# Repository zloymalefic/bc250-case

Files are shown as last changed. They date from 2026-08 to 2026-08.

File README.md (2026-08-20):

# BC-250 + JF13K compact case

Engineering project for a compact, quiet, 3D-printable Steam Machine-style enclosure built around:

`AMD BC-250 + mounting adapter + JIUSHARK JF13K + modular PSU`

The design is in a controlled recovery and geometry-validation phase. There is currently no printable enclosure release. Previous prototype exports were withdrawn because their mating interfaces did not form a buildable assembly; see [cad/ASSEMBLY-AUDIT.md](cad/ASSEMBLY-AUDIT.md).

## Based on and inspired by

This enclosure is explicitly based on and inspired by two primary community projects:

- [nyacom's AMD BC-250 Industrial Style Case for FlexATX](https://www.printables.com/model/1737913-nyacoms-amd-bc-250-industrial-style-case-for-flexa) - primary exterior design, proportions, end-ring language, and removable-cover concept;
- [NexGen3D DIY Steam Machine PRO V2](https://www.printables.com/model/1793043-nexgen3d-diy-steam-machine-pro-v2-liquid-cooled-bc/files) - power-button assembly, serviceable snap/slot panels, universal PSU mounting strategy, and modular internal architecture.

The later [NexGen3D REDUX Edition](https://www.printables.com/model/1649679-nexgen3d-diy-steam-machine-redux-edition) is retained as a revision cross-check for mechanisms already adopted from PRO V2, plus its editable blank button and later storage/split-cover refinements.

Additional source projects, direct links, adopted features, pinned revisions, and licensing notes are documented in [ATTRIBUTION.md](ATTRIBUTION.md) and [SOURCES.md](SOURCES.md). This is an independent community derivative and is not an official product of the referenced creators or hardware vendors.

## Current direction

- Common chassis for the BC-250 and JF13K assembly.
- Replaceable horizontal and vertical support/base modules.
- Independent replaceable PSU carriers, initially for Cisco UCSC-PSU-650W V02 and later FlexATX.
- Vertical BC-250/JF13K assembly with controlled intake through the broad side panel.
- Serviceable front USB hub, 2.5-inch drive mount, and ESP32 relay-controller tray.

## Интерактивная 3D-визуализация

В репозитории есть браузерный viewer текущей компоновки корпуса. Он позволяет
вращать сборку, разносить детали, переключать заднюю крышку и независимо
скрывать элементы через легенду.

### Быстрый запуск

Требуются Python 3.10+ и современный браузер с WebGL 2. Для обычного просмотра
OpenSCAD не нужен: viewer использует готовые STL из `visualization/assets/`.

```sh
git clone <URL-РЕПОЗИТОРИЯ> bc250-case
cd bc250-case
python3 tools/dev_visualization.py
```

Открыть <http://localhost:8000/visualization/>. Сервер доступен только локально
на `127.0.0.1`. Для остановки нажать `Ctrl+C`. Другой порт:

```sh
python3 tools/dev_visualization.py --port 8080
```

Three.js загружается с jsDelivr, поэтому при первом открытии страницы требуется
доступ в интернет. Открывать `visualization/index.html` через `file://` нельзя:
браузер заблокирует загрузку STL.

### Управление viewer

- ЛКМ — вращение, колесо — масштаб, ПКМ — сдвиг камеры.
- Кнопки «Спереди», «Сбоку», «Сзади» и «3/4» выбирают готовый ракурс.
- «Разнести детали» показывает взаимное расположение компонентов.
- «Каркас корпуса» и «Внутренние компоненты» управляют крупными слоями.
- Каждая строка легенды отдельно скрывает или показывает соответствующий элемент.
- В блоке «Задняя крышка» выбирается горизонтальный, вертикальный вариант либо
  полностью снятая крышка.

### Обновление моделей

`cad/` и `cad-visualization/` являются исходниками, а
`visualization/assets/*.stl` — производными файлами только для рендеринга.
Обычный сервер не запускает OpenSCAD и не пересобирает CAD автоматически.

Полная сверка и обновление производных STL выполняются только явно:

```sh
tools/up-model
```

Команда собирает модели во временном каталоге, сравнивает геометрию и атомарно
заменяет только отличающиеся файлы в `visualization/assets/`. Исходные каталоги
она не изменяет. Проверка без замены файлов:

```sh
tools/up-model --check
```

Для пересборки требуется OpenSCAD в `PATH`. Установка на macOS:

```sh
brew install --cask openscad
```

На Ubuntu/Debian: `sudo apt install openscad`. Ручной совместимый entrypoint —
`tools/export_visualization_assets.sh`. После обновления STL запущенный viewer
сам перезагрузит страницу. Цвета и расположение объектов на сцене задаются в
`visualization/viewer.js` и не требуют изменения или повторного экспорта STL.

Полная инструкция, включая установку внешней mesh-модели BC-250 и решение
типичных проблем: [visualization/SETUP.md](visualization/SETUP.md).

Согласованные проекции корпуса v0.3

## Project files

- `BC-250-JF13K-agent-context.md` - original project context and priorities.
- `DESIGN-BRIEF.md` - evolving engineering requirements plus mandatory
  enclosure-envelope, mating-interface, physical-support, structural-strength,
  and airflow validation rules.
- `BOM.md` - provisional fastener, consumable, filament, electronics, and procurement list with project article numbers and quantities.
- `SOURCES.md` - reference registry, pinned revisions, formats, licenses, and preliminary measurements.
- `ATTRIBUTION.md` - complete credits, direct links, adopted features, and derivative-license notices.
- `docs/FINAL-VISUALIZATION.md` - final Blender/GLB rendering, viewing, and exploded-view delivery plan.
- `TECHNICAL-REPORT-01.md` - superseded horizontal layout study retained as design history.
- `cad/layout-a-envelope.scad` - parameterized collision/envelope model for layout A.
- `cad/exterior-nyacom-v0.2.scad` - replacement exterior direction closely based on the Nyacom industrial case language.
- `cad/NYACOM-ADAPTATION.md` - retained design features, necessary JF13K changes, and derivative-license note.
- `cad/JF13K-PHOTO-FIT.md` - official JF13K envelope, photo/board-model cross-check,
  panel clearance, and remaining physical sanity checks.
- `cad/power-button-nexgen-v0.1.scad` - recreated three-part, backlit, rotatable NexGen-style button module.
- `cad/psu-universal-internal-v0.2.scad` - internal receiver for the common
  NexGen 110 × 46.34 mm server/FlexATX/LOP adapter family.
- `cad/NEXGEN-MECHANISMS.md` - exact NexGen mechanisms selected for reuse and their project-specific constraints.
- `cad/PSU-INTERFACE.md` - fully internal PSU interface and flush-rear requirement.
- `cad/chassis-split-v0.1.scad` - front/rear printable structural sections with an internal alignment collar.
- `cad/CHASSIS-SPLIT.md` - split location, print envelopes, clearance, and retention details.
- `cad/chassis-joint-coupon-v0.1.scad` - reduced-cost three-clearance test of the real chamfered chassis joint.
- `cad/intake-panel-snap-v0.1.scad` - two independently replaceable JF13K intake halves with hidden hooks.
- `cad/fit-calibration-coupon-v0.1.scad` - combined M3/M4 insert, screw-hole, and snap-clearance pre-production test.
- `cad/front-service-module-v0.1.scad` - full-section sculpted Nyacom-derived front cap with an integrated NexGen button and USB cassette.
- `cad/rear-service-blanks-v0.1.scad` - two vertical snap-in board/I/O and PSU
  blanks shared by both rear-cover variants.
- `cad/board-spine-v0.1.scad` - split vertical BC-250 carrier using the verified
  308.0 × 144.3 mm bare-PCB envelope and an open backplate area.
- `cad/BC250-DATUM.md` - dimensional source audit and restricted-reference
  handling rules.
- `docs/JF13K-MEASUREMENT-GUIDE.md` - step-by-step Russian measurement and photo
  checklist for an already assembled BC-250 + JF13K module.
- `cad/USB-RETURN-INTERFACE.md` - dual 180-degree adapter envelope and the
  replaceable-insert rule derived from NexGen and seller data.
- `cad/peripheral-bay-v0.1.scad` - removable 7 mm SSD and ESP32 relay-board cassettes.
- `cad/REAR-COVER-VARIANTS.md` - shared portrait I/O/PSU openings and the
  horizontal versus tapered vertical rear-cover construction.
- `cad/ASSEMBLY-AUDIT.md` - authoritative compatibility audit and recovery order.
- `cad/core-assembly-v0.1.scad` - active single-source rebuild of the two-part structural core and accessible seam retention.
- `cad/CORE-ASSEMBLY.md` - core assembly sequence, closed interfaces, and remaining work.
- `cad/REDUX-ADAPTATION.md` - selected Redux mechanisms, measured envelopes, and adaptation constraints.
- `cad/exports/README.md` - authoritative list of STL files currently approved for slicing.
- `cad/support-horizontal.scad` and `cad/support-vertical.scad` - interchangeable support prototypes using a common M4 interface.
- `cad/SUPPORT-INTERFACE.md` - dimensions, fasteners, and unresolved validation points for both orientations.
- `cad/previews/exterior-orthographic-v0.3.svg` - four orthographic projections
  at one scale plus a tower-orientation schematic derived from the left view.
- `references/printables-*` - downloaded reference models retained with their source PDFs and license information.
- `tools/inspect_3mf.py` - small utility for reporting raw 3MF vertex bounds.

## Important

The repository contains third-party reference files under different licenses. Review `SOURCES.md` and the source PDF in each reference directory before reusing or redistributing a model. Reference geometry is not automatically part of the final case design.

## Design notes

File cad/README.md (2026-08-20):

# CAD workspace

Current status: **design recovery; no printable enclosure release**.

## Verification before printing

Run `python3 tools/verify_model.py` from the repository root. It compiles the
assembly constraints and checks nine critical generated STL files for contract
envelopes, degenerate triangles, open/non-manifold edges and the 250 mm print
ceiling. Only `MODEL VERIFICATION PASSED` is an acceptable result.

`tools/export_visualization_assets.sh` runs the same verification automatically.
All twenty parts are generated in a temporary directory first. Viewer assets
are replaced only after the complete set passes, so an invalid rebuild cannot
overwrite the last verified STL files.

Mechanical mating dimensions live in `lib/interface-contracts.scad`. The front
panel/button/USB interfaces, intake covers/gap/magnets, ESP32 cover/opening,
rear covers and universal PSU receiver consume these shared values.

Read `ASSEMBLY-AUDIT.md` before using any model. It records why the previous collection could not be assembled and defines the recovery order.

## Safe outputs

Only the small test pieces in `exports/` are currently approved for slicing. See `exports/README.md`.

```sh
openscad -o exports/fit-calibration-coupon-v0.1.stl fit-calibration-coupon-v0.1.scad
openscad -D 'clearances=[0.25]' -o exports/chassis-joint-coupon-0.25mm-v0.1.stl chassis-joint-coupon-v0.1.scad
openscad -D 'clearances=[0.35]' -o exports/chassis-joint-coupon-0.35mm-v0.1.stl chassis-joint-coupon-v0.1.scad
openscad -D 'clearances=[0.45]' -o exports/chassis-joint-coupon-0.45mm-v0.1.stl chassis-joint-coupon-v0.1.scad
```

## Retained studies

Other `.scad` files are non-release studies. They preserve useful dimensions and geometry for rebuilding the master assembly, but their interfaces are incomplete. Successful OpenSCAD compilation does not make a study printable or compatible with another study.

The exterior direction is documented by
`previews/exterior-orthographic-v0.3.svg`: four separate orthographic views at a
common 2 px/mm scale and a tower schematic obtained by rotating the left-side
projection. It is a dimensional architecture preview, not a manufacturing
drawing.

## Active rebuild

`core-assembly-v0.1.scad` is the active master for the two structural halves. It replaces the inaccessible axial joint with two bottom-access M3 fasteners. See `CORE-ASSEMBLY.md`. It remains validation-only until end panels and internal mounting interfaces are integrated.

The same master now includes two interchangeable rear-cover structures:
`rear-cover-horizontal` and `rear-cover-vertical`. The latter becomes a 44 mm
open cable-management base when the complete enclosure is stood on its rear
face. See `REAR-COVER-VARIANTS.md`.

`HEATSINK-MOUNT-COMPARISON.md` compares the supplied Sean MK7/RZ620 mount with
the previously supplied AN600 adapter and records why neither may yet be treated
as a verified JF13K production mount.

`board-spine-v0.1.scad` is the first dimensional vertical carrier based on the
308.0 × 144.3 × 1.6 mm bare-PCB envelope. `BC250-DATUM.md` records the source,
license boundary, open-reference cross-check, and remaining retention risk.

`psu-universal-internal-v0.2.scad` replaces the provisional long rail with a
fully internal receiver for the NexGen 110 × 46.34 mm interchangeable PSU mount
family. It accepts server, FlexATX, and Mean Well plate depths without requiring
the Cisco PSU body to be measured.

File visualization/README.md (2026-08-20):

# BC-250 browser 3D viewer

Русская инструкция по установке и совместной работе: [`SETUP.md`](SETUP.md).

Быстрый запуск из корня репозитория:

```sh
python3 tools/dev_visualization.py
```

Открыть: <http://localhost:8000/visualization/>

Сервер следит за интерфейсом и готовыми STL и автоматически обновляет открытую
страницу. CAD автоматически не пересобирается.

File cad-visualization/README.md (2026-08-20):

# Visualization-only CAD sources

This directory contains non-printable geometry used only to prepare browser
rendering assets. Files here must not be treated as manufacturing models.

- `cad/` is the authoritative engineering CAD source.
- `cad-visualization/` contains visualization-only wrappers and decorative meshes.
- `visualization/assets/` contains generated render assets and is never authoritative.

The visualization agent treats both `cad/` and `cad-visualization/` as
read-only. Missing or incompatible source geometry must be reported instead of
being silently replaced or adjusted for appearance.

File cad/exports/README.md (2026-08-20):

# Validation exports only

There is currently no printable case release in this directory.

The retained files are small calibration objects:

- `fit-calibration-coupon-v0.1.stl` — M3/M4 holes, heat-set pilots, and snap clearances;
- `chassis-joint-coupon-0.25mm-v0.1.stl`;
- `chassis-joint-coupon-0.35mm-v0.1.stl`;
- `chassis-joint-coupon-0.45mm-v0.1.stl`.

Do not combine these into a case assembly. Release parts will appear under `exports/release/<version>/` only after a complete master-assembly check.

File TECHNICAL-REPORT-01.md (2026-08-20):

# Первый технический отчёт: BC-250 + JF13K — устаревшая компоновка

> Отменено 2026-08-20. В выбранной архитектуре Nyacom плата BC-250 и основные компоненты установлены вертикально вдоль длинной оси корпуса. Горизонтальная двухуровневая рекомендация ниже сохранена только как история исследования и не должна использоваться в текущем CAD.

Дата: 2026-08-19  
Статус: компоновочное исследование до физического fit-check.

## 1. Вывод

Рекомендуемая архитектура — **продольный двухуровневый chassis**: BC-250 и JF13K образуют верхний функциональный модуль, а Cisco PSU устанавливается вдоль платы в отдельном нижнем канале. Горизонтальная и вертикальная версии используют один chassis и отличаются только внешней опорой/нижней панелью. PSU, SSD и контроллер питания устанавливаются на отдельных сменных кассетах.

Предварительный внешний envelope рекомендуемой версии: **около 330 × 155 × 195 мм, 10,0 л**. Поперечное сечение сделано уже и выше, чтобы сохранить характерные пропорции Nyacom вместо квадратного тоннеля. Размер всё ещё предварительный: высота зависит от фактической установки кулера и разъёмов Cisco PSU.

## 2. Таблица размеров

| Узел | Размер, мм | Статус | Источник / примечание |
|---|---:|---|---|
| BC-250, proxy-envelope с компонентами | 311,7 × 144 × 31,8 | подтверждено по локальной mesh-модели | `references/hafriedlander-bc250-case/_extern/bc250_alt.stl`; требует сверки с независимым STEP |
| JIUSHARK JF13K Diamond | 241 × 121 × 92 | подтверждено производителем | https://www.jiushark.com/products/jf13k.html |
| JF13K, масса | 895 г | подтверждено производителем | тот же источник |
| JF13K, вентиляторы | 2 × 120 × 120 × 15 | подтверждено производителем | тот же источник |
| AN600-to-BC250 adapter | 105 × 105 × 8 | подтверждено по STL и 3MF | Printables 1707972, обе модели совпадают по bounds |
| Cisco UCSC-PSU-650W V02 | около 240 × 96 × 40 | предварительно | открытые источники смешивают близкие DPS-650AB-2 revisions; обязательно измерить экземпляр |
| 2,5″ накопитель | около 100 × 70 × 7–15 | стандартный envelope | точная толщина зависит от устройства |
| ESP32-WROOM + 2 relay PCB | до 60 × 60 | предварительно по карточке товара | отверстия и высоту клемм измерить после покупки |
| Nyacom FlexATX reference case | 125 × 315 × 175 | подтверждено по STL envelope | около 6,9 л, штатный heatsink |
| NexGen PRO V2 reference case | около 329 × 109 × 282 | расчёт по отдельным 3MF | около 10,15 л; сборочные transforms требуют осторожности |
| Quiet Tower reference case | 180 × 368 × 269 | подтверждено по assembled STL | около 17,8 л |

## 3. Envelope узла BC-250 + adapter + JF13K

### Плановая проекция

- BC-250 proxy-envelope: 311,7 × 144 мм.
- JF13K: 241 × 121 мм.
- При подтверждённой параллельной установке JF13K кулер должен помещаться внутри продольного envelope платы либо давать небольшое локальное нависание, не определяющее полную длину корпуса.
- Минимальный расчётный внутренний план chassis: **320 × 150 мм**.
- Практический план с рёбрами, панелями и допусками: **325–330 × 160–170 мм**.

### Высота

- Номинальные 92 мм JF13K относятся к стандартной socket installation.
- Адаптер имеет толщину 8 мм, но нельзя просто сложить 92 + 8: часть высоты входит в монтажный stack и зависит от планок, проставок и coldplate.
- До измерения использовать расчётный front-side envelope **100–110 мм от плоскости PCB**.
- Под PCB требуется 12–18 мм для backplate, электрических зазоров и воздушного канала.
- Без PSU расчётная толщина модуля: **115–130 мм**.

### Сервисные зоны

- Не менее 15 мм около силового 8-pin разъёма до начала радиуса изгиба углового адаптера/кабеля.
- Съёмная панель над крепёжными точками либо возможность вынуть весь tray платы без снятия JF13K.
- Зона отвёртки зависит от того, затягивается ли JF13K со стороны backplate; доступ должен сохраняться до установки нижнего PSU-tray.
- Локальная ниша под 180°/90° USB-A адаптер с механической разгрузкой порта.

## 4. Совместимость AN600 adapter с JF13K

### Что подтверждено

- Адаптер связывает четыре точки BC-250 с Intel mounting bars от AN600.
- JF13K комплектуется Intel LGA1700 bars и использует заднюю затяжку.
- В сообществе показана работоспособная установка JF13K на BC-250 через LGA1700-to-BC250 adapter.

### Что не подтверждено

- Совпадение отверстий Intel bars JF13K с внутренними отверстиями конкретного STL AN600.
- Возможность использовать STL без снятия чёрных элементов штатного крепления.
- Толщина проставок: в практическом сообщении упомянуты четыре spacer 1–2 мм.
- Длина винтов, остаточный ход пружин и допустимое усилие прижима.
- Полный контакт coldplate с APU без перекоса.

### Инженерный вывод

Совместимость **условно подтверждена на уровне монтажного принципа**, но не подтверждена для неизменённого комплекта деталей. Первый печатный объект проекта должен быть не корпусом, а адаптером и набором калибровочных проставок 1,0 / 1,5 / 2,0 мм.

## 5. Варианты компоновки

### A. Продольный двухуровневый chassis — рекомендация

Ориентировочный размер: **330 × 155 × 195 мм (~10,0 л)**.

- BC-250 + JF13K сверху.
- Cisco PSU продольно под PCB, ближе к одному краю.
- Рядом с PSU в нижнем канале: ESP32 relay tray и опциональный 2,5″ tray.
- JF13K получает воздух через большую верхнюю/боковую mesh-панель.
- Горячий воздух выходит через торцы и контролируемую зону вокруг I/O.
- PSU получает собственный холодный воздух снизу/сзади и не питается выхлопом JF13K.
- Горизонтальная версия использует ножки и нижнюю панель; вертикальная — сменную широкую опору на короткой грани.

Плюсы: компактность, короткие силовые кабели, общий chassis для двух ориентаций, хорошая защита тяжёлого кулера.  
Риски: общая высота; нужно изолировать intake PSU от backplate exhaust; обслуживание нижнего канала требует отдельной крышки.

### B. Плоский sidecar

Ориентировочный размер: **330 × 265 × 125 мм (~10,9 л)**.

- PSU расположен рядом с BC-250 в одной плоскости.
- JF13K остаётся единственным высоким узлом.
- SSD и ESP32 размещаются в полосе между PSU и I/O либо на съёмной поперечной балке.
- Intake JF13K и PSU полностью независимы.

Плюсы: минимальная толщина, лучший сервисный доступ, простые воздушные каналы.  
Риски: большая площадь на столе, менее выразительная вертикальная версия, длиннее силовая трасса, сложнее уложиться в типовой стол 250 мм одной крупной деталью.

### C. Полуоткрытый PSU-spine

Ориентировочный bounding box: **330 × 210 × 135 мм (~9,4 л)**, форма неполного прямоугольника.

- Основной модуль BC-250 + JF13K остаётся тонким.
- Cisco PSU находится в выступающем внешнем spine/кассете вдоль заднего края.
- Spine одновременно является ручкой/силовой балкой и меняется на FlexATX-модуль.
- SSD и ESP32 находятся за отдельной сервисной крышкой в spine.

Плюсы: лучший доступ к PSU, минимальная тепловая связь, простая замена PSU.  
Риски: хуже внешний вид, выступ усложняет вертикальную опору, больше риск повреждения PSU/разъёмов при переноске, сложнее обеспечить общую жёсткость.

## 6. Airflow рекомендуемой архитектуры

Основной поток:

`наружный воздух → mesh с зазором 7–10 мм → 2×120 мм JF13K → радиатор → лицевая сторона BC-250 → торцевые exhaust-зоны`

Отдельный нижний поток:

`нижний/задний intake → Cisco PSU → собственный exhaust наружу`

Backplate:

- под PCB оставить непрерывный канал высотой 12–18 мм;
- часть давления после JF13K направить в входные окна канала;
- предусмотреть, но не комплектовать, место под 80/92-мм вентилятор;
- решение об установке вентилятора принимать после температуры backplate/памяти.

## 7. Переиспользуемые решения

### Из Nyacom

- двухчастный продольный корпус;
- магнитная декоративная панель и направляющие;
- скользящее крепление 2,5″/3,5″ как принцип;
- отдельные варианты панелей и резервный backplate fan mount.

Прямое копирование деталей ограничено CC BY-NC-SA и несовместимой геометрией штатного охлаждения.

### Из NexGen PRO V2

- единое внутреннее PSU-шасси со сменными адаптерами; в нашей реализации оно полностью утоплено в корпус;
- обязательная access panel на скрытых защёлках, без внешних болтов;
- трёхдетальная поворотная кнопка с подсветкой;
- сменные faceplates;
- щелевые вертикальные/горизонтальные опоры;
- multipurpose bay для USB/SSD/ESP;
- резьбовые вставки и повторяемый M3-крепёж.

Прямое копирование ограничено CC BY-NC; архитектурные принципы будут реализованы заново.

### Новые детали

- несущий chassis под JF13K;
- усиленный board tray и транспортные упоры кулера;
- intake panel на 2×120 мм;
- канал backplate;
- кассета Cisco UCSC-PSU-650W V02;
- кассета FlexATX;
- horizontal base и vertical stand;
- USB-hub faceplate и фиксатор углового USB adapter;
- ESP32 relay tray;
- адаптер/проставки JF13K.

## 8. Риски

| Риск | Мера |
|---|---|
| Изгиб PCB от 895-граммового JF13K | жёсткий perimeter tray, backplate load spreader, транспортные упоры радиатора |
| Неравномерный прижим APU | калибровочные проставки, контролируемая последовательность затяжки, проверка отпечатка TIM |
| Горячая обратная сторона/память | канал 12–18 мм, датчики, резерв 80/92 мм |
| Рециркуляция | разделённые intake/exhaust, уплотнение вокруг JF13K intake |
| Шум mesh | свободная площадь ≥1,5× площади вентиляторов, скруглённые ячейки, тест зазора 7/10/15 мм |
| Шум server PSU | независимый intake; не модифицировать вентилятор до измерения температуры и PWM behavior |
| Повреждение USB порта | печатный фиксатор углового адаптера и strain relief кабеля |
| Недоступность конкретного USB hub | сменная малая faceplate/cassette |

## 9. План open-bench испытаний

1. Fit-check адаптера без включения: отверстия, coldplate, зазоры, полный ход винтов.
2. Проверка отпечатка термоинтерфейса и параллельности coldplate.
3. Горизонтальный open-bench: 15 минут idle, 30 минут игровая нагрузка, 20 минут комбинированная CPU+GPU нагрузка.
4. Повторить вертикально, контролируя изменение контакта и изгиб.
5. Логировать APU/GPU, доступные VRM/board sensors, NVMe, обороты обоих JF13K fans и PSU.
6. Измерять backplate термопарой/термистором минимум в центре и около памяти; ИК-камера полезна, но не заменяет контактный датчик на блестящем металле.
7. Шум измерять с 0,5 м и 1 м, фиксируя фон помещения и обороты.
8. Сравнить mesh gaps 7 / 10 / 15 мм и временно закрывать альтернативные exhaust-зоны для выявления рециркуляции.
9. Критерий дополнительного 80/92-мм вентилятора: устойчивое улучшение backplate/памяти без заметного роста шума и без ухудшения APU.

## 10. Неизвестные параметры

- фактическая высота JF13K над PCB с этим адаптером;
- точные JF13K mounting-bar отверстия и винты;
- фактическое направление airflow Cisco PSU; механическая посадка теперь
  выполняется через универсальный адаптер NexGen 110 × 46,34 мм без обмера корпуса;
- положение JF13K относительно концов PCB и I/O;
- изгиб/радиус реального 8-pin кабеля;
- габариты выбранного USB hub;
- размеры ESP32 relay PCB и клемм;
- желаемый максимум внешнего объёма и массы корпуса.

## 11. Решение до получения новых данных

Продолжать с архитектурой A как baseline, но CAD вести параметрически. Не фиксировать высоту корпуса и отверстия JF13K до фотографий/измерений установленного узла. Первым прототипом сделать adapter fit-check, вторым — плоский board tray с каналом backplate, третьим — PSU cassette. Полный декоративный корпус печатать только после этих трёх проверок.

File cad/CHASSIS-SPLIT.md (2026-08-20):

# Split chassis interface v0.1

> Historical prototype. The released working source is now
> `core-assembly-v0.1.scad`; its split intake, central rib and receiver pockets
> supersede the single 266 × 119 mm opening described below.

The 330 mm Nyacom-style structural tunnel is divided at X=165 mm:

- front section nominal print envelope: 174 × 155 × 195 mm, including its alignment collar;
- rear section nominal print envelope: 165 × 155 × 195 mm;
- both fit within the preliminary 250 × 250 × 250 mm part limit;
- a 9 mm internal octagonal collar aligns all eight shell faces;
- the collar overlaps 1.2 mm into the front shell so it is one fused printable solid rather than a coincident mesh;
- initial radial assembly clearance is 0.35 mm per side;
- the current axial M3 bosses are an obsolete prototype and will be replaced by bottom-access fasteners close to the seam.

## Functional interfaces added

- JF13K intake opening: 266 × 119 mm;
- eight magnet bosses matching the two four-magnet intake panels, plus four longitudinal guide tongues;
- receiver blocks are integrated into the inner top perimeter, not glued-on parts;
- continuous internal tray ledges run along both lower side walls;
- ledge top is Z=49 mm, matching the integrated board-tray origin;
- the intake opening and magnet pattern cross the chassis split without placing a pocket directly on the joint.
- four 13 mm reinforced floor bosses provide the corrected 258 × 99 mm horizontal-support pattern;
- bosses accept M4 clearance screws and provisional 5.6 mm heat-set-insert pilots installed from inside.

The collar clearance is provisional. Before rebuilding complete shell exports, print the three `exports/chassis-joint-coupon-*-v0.1.stl` pairs at 0.25, 0.35, and 0.45 mm clearance per side.

Magnet-pocket allowance remains provisional. Full chassis printing must wait until an 8.25 × 2.20 mm pocket coupon is tested with the selected material, print service, magnet coating and adhesive.

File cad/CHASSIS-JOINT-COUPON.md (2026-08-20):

# Chassis joint coupon v0.1

The complete chassis sections are too large and expensive to use as calibration prints. `chassis-joint-coupon-v0.1.scad` therefore extracts the actual bottom-left chamfered corner of the shell and collar.

The export set contains three labelled STL files, each with one male/female pair. Their radial clearances are 0.25, 0.35, and 0.45 mm per side. Every pair includes the real 4 mm shell, 2.4 mm collar wall, chamfer transition, 9 mm insertion length, and a fused anchor extending 1.2 mm into the front shell.

## Procedure

1. Print the three `chassis-joint-coupon-*-v0.1.stl` files together; each file is one matched pair.
2. Print using the final chassis material, orientation, layer height, wall count, and cooling settings.
3. Deburr only the same way planned for production; do not sand a poor fit into compliance.
4. Insert fully, separate, and repeat at least ten times.
5. Select the smallest clearance that seats fully by hand without cracking, whitening, or rocking after repeated cycles.
6. Record the result in the table and update `collar_clearance` in `chassis-split-v0.1.scad`.

| Clearance per side | Seats fully | Releases cleanly | Visible play | Damage after 10 cycles | Decision |
|---:|---|---|---|---|---|
| 0.25 mm | — | — | — | — | — |
| 0.35 mm | — | — | — | — | — |
| 0.45 mm | — | — | — | — | — |

The obsolete axial M3 boss concept is intentionally absent. A production screw cannot practically be inserted along the full enclosure length. Structural retention will use bottom-access fasteners close to the seam and remain hidden by the horizontal or vertical support system.

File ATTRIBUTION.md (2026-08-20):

# Credits, inspiration, and attribution

This project is not designed in isolation. It is based on, adapted from, and inspired by the BC-250 community projects listed below. Their authors established much of the visual language, service architecture, mounting strategy, and source geometry used during development.

## Primary exterior reference

### nyacom - AMD BC-250 Industrial Style Case for FlexATX

- Source: https://www.printables.com/model/1737913-nyacoms-amd-bc-250-industrial-style-case-for-flexa
- License: CC BY-NC-SA 4.0, as identified in the supplied Printables package.
- Used for: industrial exterior language, long octagonal tunnel, contrasting end rings, recessed end panels, removable broad-side cover, sliding storage-mount principle, and general compact proportions.
- Project-specific adaptation: enlarged and restructured around the JIUSHARK JF13K, split for smaller print beds, and combined with NexGen-derived service mechanisms.

## Primary mechanical reference

### NexGen-3D-Printing - DIY Steam Machine REDUX Edition (later revision cross-check)

- Source: https://www.printables.com/model/1649679-nexgen3d-diy-steam-machine-redux-edition
- License: CC BY-NC 4.0, as identified in the supplied package.
- Used to compare later revisions of mechanisms already adopted from PRO V2. Additional useful files are the editable blank button, improved snap tabs, split-cover joiners, and storage caddy.
- Adaptation notes: `cad/REDUX-ADAPTATION.md`.
- No Redux mesh is currently included in a release part.

### NexGen-3D-Printing - DIY Steam Machine PRO V2

- Printables files: https://www.printables.com/model/1793043-nexgen3d-diy-steam-machine-pro-v2-liquid-cooled-bc/files
- GitHub: https://github.com/NexGen-3D-Printing/SteamMachine
- License: CC BY-NC 4.0, as identified in the supplied Printables package.
- Used for: replaceable PSU mounts, internal multipurpose bay, access-panel strategy, snap/slot panel servicing, vertical and horizontal support concepts, and the three-part backlit power button.
- Directly reused asset: `Power Button/pro-v2-steam-logo.3mf`, retained in the local reference package and imported by `cad/power-button-nexgen-v0.1.scad`.
- Project-specific adaptation: the common PSU chassis is fully internal; no PSU carrier is allowed to protrude through the Nyacom-style rear ring.

## Additional geometry and engineering references

### hafriedlander - bc250-case

- Source: https://github.com/hafriedlander/bc250-case
- Used for: BC-250 proxy geometry, OpenSCAD construction study, and preliminary envelope validation.
- No standalone license was found in the pinned local revision; its geometry is therefore treated as an engineering reference and is not presented as original project geometry.

### onemorecap - bc-250-shell-case

- Source: https://github.com/onemorecap/bc-250-shell-case
- Used for: editable chassis, mounting, and print-splitting study.
- No standalone license was found in the pinned local revision; its geometry is treated as reference-only.

### DeepCool AN600 adapter for AMD BC-250

- Source: https://www.printables.com/model/1707972-deepcool-an600-adapter-for-amd-bc-250
- License: Public Domain, as identified in the supplied Printables package.
- Used for: the initial LGA1700-style cooler-interface study and JF13K fit-check planning.

### Sean - BC-250 Heat Sink Mount (MK7)

- Source: https://www.printables.com/model/1217021-bc-250-heat-sink-mount
- License: Public Domain, as identified in the supplied Printables PDF.
- Used for: independent BC-250 heatsink-footprint comparison and M4 fastening
  study. It is not treated as a JF13K-compatible production adapter.

### torassk - Accurate 3D Model of the AMD BC-250 Board

- Source: https://www.printables.com/model/1341336-accurate-3d-model-of-the-amd-bc-250-board
- License: Standard Digital File License in the supplied PDF.
- Used locally only to cross-check factual board dimensions. No source file,
  converted model, or linked derivative is hosted in this repository.

### BC-250 Quiet Case Tower Cooler

- Source: https://www.printables.com/model/1652979
- License: CC BY-NC 4.0, as identified in the supplied Printables package.
- Used for: front USB routing, large-air-cooler packaging, and auxiliary-storage study.

### zloymalefic - BC-250 PC Remote Control

- Source: https://github.com/zloymalefic/BC-250-PC-Remote-Control
- Used for: ESP32 relay-controller integration, remote power control, and front-button electrical planning.

## Project status and licensing note

The current repository contains engineering studies, recreated interfaces, derivative visual design, and third-party reference packages. It is not an official product of nyacom, NexGen-3D-Printing, Valve, AMD, ASRock, Cisco, or JIUSHARK.

Any distribution or remix of derivative case geometry must preserve the attribution, non-commercial, and share-alike obligations applicable to the Nyacom-derived portions. Direct NexGen assets, including the Steam-logo button component, retain their original attribution and license requirements. Review each source package before redistributing individual third-party files.

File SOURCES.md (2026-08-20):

# Реестр инженерных источников

Статус на 2026-08-19. Наличие файла не означает подтверждение его точности или разрешение на прямое переиспользование.

## Получено локально

| Источник | Форматы | Полезность | Статус лицензии |
|---|---|---|---|
| [hafriedlander/bc250-case](https://github.com/hafriedlander/bc250-case) | OpenSCAD, STL, изображения | Детальная proxy-модель BC-250, параметрический корпус, кронштейны | Отдельный LICENSE в репозитории не найден; прямое копирование деталей пока запрещено |
| [onemorecap/bc-250-shell-case](https://github.com/onemorecap/bc-250-shell-case) | STEP, 3MF, STL, изображения | Редактируемый модульный chassis, крепёж и разбиение для печати | Отдельный LICENSE в репозитории не найден; прямое копирование деталей пока запрещено |
| [NexGen-3D-Printing/SteamMachine](https://github.com/NexGen-3D-Printing/SteamMachine) | README, XLSX BOM, 3MF, архивы | Принципы модульности, PSU-модули, faceplates, обслуживание | CAD-пакет Printables: CC BY-NC 4.0 |
| [zloymalefic/BC-250-PC-Remote-Control](https://github.com/zloymalefic/BC-250-PC-Remote-Control) | Arduino/C++, HTML/CSS | Электрические интерфейсы контроллера питания и кнопки | Используется как связанный пользовательский проект; геометрия платы пока внешняя |

Зафиксированные ревизии:

- hafriedlander: `cf807f35897c43f5c489bf60b8fa54bf1fba0f00`;
- onemorecap: `ea2e59bab5ea5f5bd4cfce69b72c4a192391daea`;
- NexGen3D: `b305ccccd7133a7ae7340d578f10b4ec820ff63a`;
- Remote Control: `793f5d05ef1bef5f4681796562bda49f6b1ef97f`.

## Получено из Printables

### NexGen3D DIY Steam Machine REDUX Edition

- Source: https://www.printables.com/model/1649679-nexgen3d-diy-steam-machine-redux-edition
- Printables model 1649679; архив распакован в `references/printables-1649679-nexgen-redux`.
- 85 файлов: V4.2/V4.2.1 3MF, STEP-заготовки faceplate/button/PSU brackets, старые ревизии и PDF.
- Статус: более поздняя ревизия механизмов, уже принятых из PRO V2. Дополнительная ценность: editable blank-button STEP, обновлённые snap-tabs, split covers и storage caddy.
- `redux-optional-usb-cover.3mf`: raw envelope около 12,65 × 70,35 × 32,58 мм.
- Лицензия: CC BY-NC 4.0.

### Nyacom Industrial Style Case for FlexATX

- Source: https://www.printables.com/model/1737913-nyacoms-amd-bc-250-industrial-style-case-for-flexa
- Printables model 1737913; полный архив распакован в `references/printables-1737913-nyacom-flex`.
- 36 STL, 2 reference 3MF и 42-страничный PDF.
- Общий envelope корпуса по STL: около 125 × 315 × 175 мм (~6,9 л), без внешних кабелей и ножек.
- 3MF помечены автором как outdated/reference; актуальными считаются отдельные STL.
- Лицензия: CC BY-NC-SA 4.0.

### NexGen3D Steam Machine PRO V2

- Files: https://www.printables.com/model/1793043-nexgen3d-diy-steam-machine-pro-v2-liquid-cooled-bc/files
- Printables model 1793043; полный архив распакован в `references/printables-1793043-nexgen-pro-v2`.
- 43 файла 3MF, 1 редактируемый STEP пустой faceplate и 15-страничный PDF.
- Примерный общий envelope front + rear: 329,1 × 109,35 × 282,1 мм (~10,15 л); требует проверки сборочных transforms.
- Присутствуют отдельные крепления server PSU/FlexATX/LOP, вертикальная подставка, access panel и multipurpose bay.
- Лицензия: CC BY-NC 4.0.

### BC-250 Quiet Case Tower Cooler

- Source: https://www.printables.com/model/1652979
- Printables model 1652979; архив распакован в `references/printables-1652979-quiet-case`.
- Это дополнительный референс, а не запрошенный адаптер AN600.
- 16 STL и 7-страничный PDF; envelope assembled STL около 180 × 368 × 269 мм (~17,8 л).
- Полезен для USB routing, большого воздушного кулера и front USB hub.
- Лицензия: CC BY-NC 4.0.

### DeepCool AN600 adapter for AMD BC-250

- Source: https://www.printables.com/model/1707972-deepcool-an600-adapter-for-amd-bc-250
- Printables model 1707972; полный архив распакован в `references/printables-1707972-an600-adapter`.
- Содержит STL, 3MF и 3-страничный PDF; редактируемого STEP/CAD нет.
- STL и 3MF имеют совпадающий envelope 105 × 105 × 8 мм.
- Рассчитан на Intel mounting brackets из комплекта DeepCool AN600.
- Крепёж автора: 4× M3×12, 4× M3×20, 8× M3 nuts.
- Лицензия: Public Domain.

### Sean BC-250 Heat Sink Mount (MK7)

- Source: https://www.printables.com/model/1217021-bc-250-heat-sink-mount
- Printables model 1217021; supplied archive extracted to
  `references/printables-1217021-heatsink-mount`.
- Contains one 105.56 × 104.39 × 8 mm STL and a 2-page Printables PDF.
- Intended for the PCCOOLER RZ620 Intel clip bracket, not the JIUSHARK JF13K.
- Author describes M4 installation from below, either self-tapped or through
  with nuts, using a mixture of cooler and removed stock-heatsink hardware.
- License in supplied PDF: Public Domain.

### torassk Accurate 3D Model of the AMD BC-250 Board

- Source: https://www.printables.com/model/1341336-accurate-3d-model-of-the-amd-bc-250-board
- The user supplied the package locally; it is intentionally not extracted into
  or committed to this repository.
- Files: STEP, STL, and a 2-page Printables PDF.
- Author states that dimensions and mounting points match the real board.
- License: Standard Digital File License; no sharing, hosting, remixing, or
  redistribution. Used only as a local dimensional cross-check.

## Доступно в каталогах, но файлы ещё не получены

## Дополнительные источники геометрии BC-250

- Printables model 1341336: accurate 3D model of AMD BC-250.
- Printables model 1537364: AMD BC-250 STEP file.
- Полученная proxy-модель `references/hafriedlander-bc250-case/_extern/BC-250.scad` сгенерирована из FreeCAD и должна быть сверена с этими двумя источниками.

## Правило использования

До проверки лицензии и геометрии внешние модели применяются только для анализа envelope, интерфейсов и архитектурных принципов. Финальные детали не копируются из источника с неясной лицензией.

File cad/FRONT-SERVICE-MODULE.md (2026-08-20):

# Front service module v0.1

The yellow Nyacom-style front insert is now independent from both service components:

- front panel: full 155 × 195 × 12 mm sculpted end cap derived from the Nyacom source mesh, scaled only in its face plane to match this enclosure;
- NexGen-derived button opening: 45.2 × 32.3 mm;
- replaceable vertical USB cassette opening: 28.6 × 71.0 mm;
- cassette face: 27.93 × 70.35 × 3 mm;
- baseline hub: Anker A7516 four-port USB 3.0, 103 × 30 × 10 mm;
- front apertures: four vertical USB-A data ports;
- four front-access countersunk M3 screws retain the main panel on its support shoulder;
- the small USB cassette can be serviced after the four front-panel screws are removed;
- authoritative shape source: `references/printables-1737913-nyacom-flex/body-front-panel.stl`;
- the NexGen 44.5 × 31.6 mm mounting plate is fastened exclusively against the
  inside face; only the light pipe/pusher and logo cap pass through to the
  exterior. A separate extension accounts for the 12 mm cap thickness.
- concealed release notches permit servicing without visible screws.
- two M3 insert bosses and edge ribs retain the NexGen-derived button plate.

NexGen PRO V2 explicitly specifies the Anker four-port hub and its supplied USB
cover measures approximately 70.35 × 27.93 × 12.65 mm. This is the current
baseline. If a cheaper hub is selected later, only the small cassette is
reworked; the 28.6 × 71.0 mm front-panel interface and its receiver rails remain
unchanged wherever possible.

The rear USB return is now specified independently in `USB-RETURN-INTERFACE.md`.
Its provisional per-adapter envelope is 32 × 30 × 29 mm plus clearance; only a
small contact insert depends on the delivered A/D variant.

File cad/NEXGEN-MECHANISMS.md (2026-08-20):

# NexGen PRO V2 mechanisms adopted by this project

Only the mechanisms below are taken from the NexGen reference. Exterior styling remains based on Nyacom model 1737913.

## Rotatable power button

The supplied NexGen files separate the module into:

- mounting plate, measured raw envelope 44.54 × 31.59 × 5.10 mm;
- transparent rear/light-pipe section, 6.00 × 19.80 × 22.06 mm in its print orientation;
- removable Steam-emblem cap, 6.20 × 16.00 × 16.00 mm in its print orientation. The original `pro-v2-steam-logo.3mf` is imported directly and retains NexGen attribution.

The project recreation uses a 16 mm switch, two M3 fasteners, separate light pipe, and removable cap. The button plate is removable from the bolted Nyacom-style front panel and can be rotated 90 degrees when the case orientation changes.

The earlier standalone exports were withdrawn during the assembly audit. The rebuilt release will keep the light pipe and Bazzite cap as separate bodies generated from the master assembly.

## Dual 180-degree USB return

PRO V2 already specifies two black 180-degree USB adapters and includes `pro-v2-usb-cover-multi-material.3mf`. This is the baseline mechanism for routing rear BC-250 USB ports back into the enclosure. Redux is only a later implementation reference, not the source of this requirement.

The selected seller lists A-D variants with maximum stated dimensions of about
32 × 30 × 29 mm, 10 Gbit/s theoretical transfer, and 3 A current. Because the
dimension list does not map axes to variants reliably, the project uses that
maximum envelope with clearance and keeps the contact insert replaceable. See
`USB-RETURN-INTERFACE.md`.

## Magnetic access panels

Routine service panels use concealed 8 × 2 mm magnets and support shoulders. The side grilles additionally use a bottom pry notch and guide tongues so magnets carry pull-off load while printed geometry carries shear. Structural chassis joints and the load-bearing rear cover may still use internal M3 screws.

## Universal internal PSU chassis

The supplied NexGen package contains separate server-PSU, FlexATX/FSP500, and Mean Well LOP mounts. This project recreates that strategy as a perforated internal rail with replaceable adapters for Cisco and FlexATX.

The major project-specific constraint is stricter: the rail, adapter, latch, PSU body, and cabling must remain inside the enclosure envelope. No PSU carrier may project through the coloured rear ring.

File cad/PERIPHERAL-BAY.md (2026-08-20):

# Peripheral bay and cassettes v0.2

## 2.5-inch storage

The active vertical architecture uses the free front pocket ahead of JF13K. The
drive stands in the Y-Z plane and slides out through the front service opening:

- supported device envelope: 100.5 × 69.9 × 15 mm maximum;
- compatible nominal thicknesses: 7, 9.5, 12.5 and 15 mm;
- open 110 × 80 × 2.4 mm bridge cassette;
- four elongated M3 slots on a 76.6 × 61.72 mm bottom pattern;
- two chassis guide walls, shallow retaining lips and a rear travel stop;
- one front-access M3 cassette screw, reached after removing the bolted front panel;
- the drive/cassette end at X=39.4 while JF13K starts at X=44.5.

The bay is outside the JF13K fan footprint and does not use the two-millimetre
PSU-to-board channel. SATA/power connector direction remains a final cable-route
check, but it does not change the cassette or body envelope.

## ESP32 relay controller

- provisional board envelope: 60 × 60 × 22 mm;
- separate 68 × 68 mm open-edge cassette;
- adjustable PCB-post slots;
- dedicated programming-USB opening;
- antenna edge remains open and faces the plastic intake side;
- horizontal position below JF13K, with 3.6 mm nominal vertical clearance;
- two bottom rails guide the cassette toward the intake side;
- a printed edge detent retains it without another screw;
- a 74 × 28 mm hidden service extension lets it slide out after the fan cover
  is removed.

The final fan-cover geometry must include a lower skirt over this service
extension down to Z=4 mm. Final post positions, connector cut-outs, and cable
restraints still require measurement of the actual combined ESP32-WROOM
dual-relay board; the adjustable cassette allows the main chassis work to
continue before that measurement.

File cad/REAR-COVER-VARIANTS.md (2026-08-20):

# Rear-cover variants v0.1

The active core has one rear interface and two interchangeable covers. This
keeps the enclosure itself unchanged when it is turned from horizontal use into
an Xbox Series X-like tower.

## Shared interface

- four M3 axes at Y = 30/125 mm and Z = 5/190 mm;
- four blind heat-set insert bosses integrated into the rear structural core;
- monolithic rear wall; final PSU and I/O cuts are made directly in each variant;
- two portrait inserts sit side-by-side inside that envelope: provisional
  openings 72 × 145 mm for board I/O and 48 × 145 mm for PSU;
- no PSU bracket or electrical connector projects outside the case envelope.

## Horizontal rear cover

The shallow 6 mm cover is flush with the case silhouette. It surrounds the
common service-cassette opening and uses four short countersunk M3 screws.

## Vertical rear/base cover

The case is rotated so its rear X+ face points down. The replacement cover is a
single red 44 mm-deep truncated-pyramid shell expanding continuously from the
155 × 195 mm rear face to a 185 × 225 mm desk footprint:

- the continuous 8 mm perimeter shell carries the enclosure load;
- the 38 mm-deep internal cavity remains open for HDMI/DP, power and USB plugs;
- two opposed side openings let cables leave without a sharp desk bend;
- the desk face has four 12 mm recesses for adhesive rubber or TPU pads;
- four bottom-access M3 screws retain the complete base.

The architecture follows the idea of DeepCool's 47.5 mm-tall Vertical Base 100
for CH160/CH170, scaled to this project's 155 × 195 mm case section. The 44 mm
depth is provisional until the longest real power/video connector is measured.

## Current validation status

This is an integrated source model, not a release STL. Before release:

1. Measure the longest connector body plus safe bend radius.
2. Print the fit coupon and select the actual M3 insert pilot.
3. Load-test the tapered perimeter shell with the assembled case mass.
4. Replace the blank service-cassette envelope with measured Cisco PSU and
   BC-250 I/O inserts.

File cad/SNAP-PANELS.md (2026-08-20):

# Magnetic intake panels v0.2

The JF13K intake is divided into two independently removable 130 × 131 mm covers:

- nominal half-panel print envelope: 130 × 131 × 4 mm;
- one 120 mm fan field per half;
- four 8 × 2 mm magnet pairs per half;
- a 5 × 2 mm bottom-edge pry notch for non-destructive removal;
- two shallow longitudinal guide channels engaging chassis tongues;
- a 10 mm visible gap exposes the structural rib retained in the shell;
- matching eight-sided cover/window outlines without a circular raised rim;
- no external panel bolts;
- a damaged half can be replaced without reprinting the other side.

Magnet pockets are 8.25 mm diameter and 2.20 mm deep. The dimensional allowance
is deliberately conservative for ordered printing and adhesive. Print a pocket
coupon with the intended material and service before committing the full covers.

The matching eight chassis magnet seats, four guide tongues and 10 mm central
rib are integrated into `core-assembly-v0.1.scad`. No magnet pocket is placed on
the front/rear chassis joint. The tongues prevent panel shear and act as local
longitudinal stiffeners around the large intake opening; the magnets only resist
pull-off force.

The historical SCAD filename `intake-panel-snap-v0.1.scad` is retained so the
existing export tooling does not break; its production geometry contains no
panel hooks.

## Deferred fan-cover depth

These two halves are separate covers above the JF13K fans, not structural walls
and not cooler supports. Their current flat 4 mm skin is only an interface
prototype. Final inner relief/stand-off is intentionally deferred until a
physical fan-side check; it may rise locally beyond the nominal body-side datum.
The released covers must not touch the fan frames, screws, blades, or wiring and
must repeat the airflow/no-contact check independently of the main chassis.

The rear/lower fan-cover half also hides the ESP32 cassette service extension.
Its local lower skirt must reach the Z=4 mm body datum over X=177–251 mm; this
requirement is frozen even though the final fan-cover depth remains deferred.

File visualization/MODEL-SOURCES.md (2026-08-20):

# Источники моделей 3D-визуализации

`visualization/assets/*.stl` — готовые файлы для браузера. Они не являются
главными CAD-исходниками: при изменении конструкции их нужно сверять и
пересобирать командой `tools/up-model`.

## Собственная CAD-геометрия проекта

| Файлы в `visualization/assets` | Исходник |
| --- | --- |
| `front-core.stl`, `rear-core.stl` | `cad/core-assembly-v0.1.scad` |
| `board-spine-front.stl`, `board-spine-rear.stl` | `cad/board-spine-v0.1.scad`, вызывается из master CAD |
| `front-panel.stl`, `front-button-mount.stl`, `front-usb-cassette.stl` | `cad/front-service-module-v0.1.scad`, вызывается из master CAD |
| `ssd-cassette.stl`, `esp32-cassette.stl` | `cad/peripheral-bay-v0.1.scad`, вызывается из master CAD |
| `esp32-cover.stl` | `cad/esp32-service-cover-v0.1.scad`, вызывается из master CAD |
| `rear-cover-horizontal.stl`, `rear-cover-vertical.stl` | `cad/core-assembly-v0.1.scad` |
| `intake-cover-left.stl`, `intake-cover-right.stl` | `cad/intake-panel-snap-v0.1.scad` |
| `button-decorative-bezel.stl` | `cad-visualization/visualization-decorative-button.scad`; только визуализация |

Главная точка входа корпуса — `cad/core-assembly-v0.1.scad`. Параметр `part`
выбирает экспортируемую деталь.

## Модели из проекта NexGen PRO V2

| Файлы в `visualization/assets` | Исходник |
| --- | --- |
| `button-plate.stl` | `references/printables-1793043-nexgen-pro-v2/Power Button/pro-v2-button-mounting-plate.3mf` |
| `button-light-pipe.stl` | `references/printables-1793043-nexgen-pro-v2/Power Button/pro-v2-transparent-rear-section.3mf` |
| `button-cap-black.stl`, `button-logo-white.stl` | `references/printables-1793043-nexgen-pro-v2/Power Button/pro-v2-steam-logo.3mf` |
| `usb-cover.stl` | `references/printables-1793043-nexgen-pro-v2/Case/pro-v2-usb-cover-multi-material.3mf` |

Промежуточные `cad/vendor/nexgen/button-*.3mf` используются только для чтения.
Updater не создаёт и не изменяет их; если они отсутствуют, он сообщает точные
пути и останавливается. Лицензия и авторство описаны в `ATTRIBUTION.md`.

## Модели, создаваемые непосредственно в viewer

Следующие объекты пока не имеют отдельных STL и строятся кодом в
`visualization/viewer.js`:

- приблизительная геометрия JIUSHARK JF13K по габариту 241 × 92 × 121 мм;
- Cisco UCSC-PSU-650W V02 как проверочный габарит 240 × 40 × 96 мм;
- Anker A7516 как габарит и четыре USB-A-разъёма;
- вентиляторы, теплотрубки и простые внутренние прокси.

Это визуальные макеты, а не печатные детали.

## Плата BC-250

Viewer локально загружает
`references/hafriedlander-bc250-case/_extern/bc250_alt.stl`. Репозиторий-источник
и зафиксированный commit указаны в `SETUP.md`. Mesh намеренно не включён в этот
репозиторий: явная лицензия на распространение не найдена.

Предоставленная пользователем точная модель платы используется для проверки
датумов и размеров, но не должна автоматически попадать в публичный релиз до
уточнения лицензии.

## Фотографии и архивы

`Photo cooler/` — исходные фотографии реально установленного JF13K. Это не
мусор и не геометрия для viewer: фотографии подтверждают ориентацию и посадку,
описанную в `cad/JF13K-PHOTO-FIT.md`.

Корневые ZIP-файлы являются только пакетами загрузки. После распаковки нужные
лицензированные материалы хранятся в `references/`; ZIP можно удалить.

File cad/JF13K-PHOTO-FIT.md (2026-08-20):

# JF13K photo fit check

## Result

The supplied photographs are sufficient to freeze the cooler envelope for the
case layout. They are not sufficient to manufacture the cooler-to-APU adapter,
which remains a separate part supplied by the builder.

The case model now uses a **241 × 92 × 121 mm** JF13K envelope in its own
coordinate system: 241 mm along the board, 92 mm away from the PCB, and 121 mm
across the board height.

With the 308.0 × 144.3 × 1.6 mm bare-PCB datum, centring this envelope gives:

| Check | Model result |
|---|---:|
| Cooler margin at each 308 mm board end | 33.5 mm |
| Cooler margin across the 144.3 mm board | 11.65 mm each side |
| Cooler top to nominal body-side datum | 9.4 mm |
| Temporarily enforced core-layout allowance | 6.0 mm |

Therefore the present 330 × 155 × 195 mm body does not need to become wider.
The covers directly above the two fans are separate magnetic components. Their
final height and inner relief are deliberately deferred, so the 9.4 mm value is
a body-layout datum rather than a frozen cover clearance. Those covers may be
locally raised if airflow or fan-screw clearance requires it.

## Evidence and confidence

- JIUSHARK's official product page specifies 241 × 121 × 92 mm and 895 g for
  JF13K: <https://www.jiushark.com/products/jf13k.html>.
- The local licensed board model gives the factual bare-PCB envelope of
  308.0 × 144.3 × 1.6 mm; the source geometry itself is not redistributed.
- The near-side photographs show the PCB plane and the fan top in one view.
  Their proportion agrees with the official 92 mm installed height; there is no
  evidence of a further large adapter-height addition.
- The near-top photograph shows the cooler inside the PCB ends and approximately
  centred across the board. The computed 33.5 mm and 11.65 mm margins match that
  observation.

Photo perspective, lens distortion, and the absence of a ruler make sub-mm
measurement impossible. For that reason photographs are used only to establish
orientation and validate the official envelope. The temporary CAD assertion
preserves at least 6 mm at the core-layout stage; the separate cover geometry
must repeat its own no-contact and airflow checks when it is finalized.

## Structural consequence

JF13K weighs 895 g. The removable intake panel must never carry or locate it.
The cooler remains attached to its APU adapter, while transport loads must pass
through the board spine/cooler support into the structural core. Final support
pad positions still require a harmless contact-zone check against the physical
radiator; this does not affect the outer case envelope.

## Remaining physical checks before printing the final case

Only three local checks remain useful; none changes the body size:

1. Verify that no fan screw or cable rises more than 3 mm above the nominal fan
   frame.
2. Route and tie the fan leads so they cannot enter either fan or cross the
   6 mm protected panel gap.
3. Check the longest studs/backplate projection on the PSU side before freezing
   the board-spine clamps.

4. Before releasing the two separate fan covers, verify their lowest internal
   point against the real spinning fan frames and preserve a visible safety gap.

The original seven-measurement guide is retained as an optional final sanity
check, not as a blocker for continuing the case CAD.

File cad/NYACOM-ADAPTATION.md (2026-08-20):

# Nyacom-inspired exterior adaptation v0.2

This replaces the generic v0.1 styling direction.

Согласованные проекции корпуса

The visual architecture deliberately follows the supplied Nyacom reference:

- a long, dark octagonal centre tunnel;
- contrasting chamfered end rings;
- recessed front and rear service panels;
- thin colour accent around the removable panel;
- a broad removable cover rather than a conventional PC side wall;
- vertical industrial vent slots and minimal exposed hardware.

The active envelope is 330 × 155 × 195 mm. Its 155:195 cross-section deliberately restores Nyacom's tall, narrow stance; the superseded 170 × 170 mm study was too square and appeared to lie on its side.

The necessary functional change is the broad JF13K intake cover. Two separated 120 mm honeycomb fields replace Nyacom's stock-cooler side-flow arrangement without abandoning the original enclosure language.

## NexGen mechanical features

- The external appearance remains Nyacom-derived.
- The power button uses the NexGen three-part, backlit, rotatable module concept.
- The Nyacom-like broad cover is retained visually and returns to the source project's magnetic service concept: four 8 × 2 mm magnet pairs per half, a bottom pry notch and anti-shear guide rails.
- A common internal PSU rail accepts separate Cisco server-PSU and FlexATX adapters.
- Unlike the referenced NexGen implementation, no PSU mount may protrude beyond the enclosure. Only a flush rear interface panel is allowed at the coloured end ring.

This is a derivative design direction based on Printables model 1737913. The reference is licensed CC BY-NC-SA; attribution, non-commercial use, and share-alike requirements therefore apply to derivative geometry. Exact copied meshes are not embedded in this concept file.

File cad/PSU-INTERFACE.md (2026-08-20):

# Fully internal universal PSU interface v0.2

The NexGen PRO V2 and Redux packages use a common 110 × 46.34 mm face for
server-PSU, FlexATX, and Mean Well adapter plates. Their raw plate depths are
21.5, 7.2, and 11.3 mm. This project recreates that interchangeable interface
inside the shell; no Cisco body measurement is required to design the receiver.

- common internal receiver: 24.85 × 118 × 54.34 mm;
- receiver supports adapter plates up to 21.5 mm deep;
- rear stop plane is X=318 mm while the exterior shell ends at X=330 mm;
- two removable interior clamp bars retain the selected adapter;
- server, FlexATX, and LOP mounts use the same receiver;
- only a flush rear connector/exhaust panel is visible from outside;
- the PSU-specific mount may be revised from the supplied NexGen adapter, but
  every feature must remain at or in front of X=318 mm.

`psu-universal-internal-v0.2.scad` remains the dimensional receiver/clamp source.
The receiver module is now fused into the rear half by
`core-assembly-v0.1.scad`; only the two clamp bars and the selected adapter plate
remain separate service parts. The actual server-PSU adapter plate can be
adapted from NexGen without changing the case or either rear-cover variant.

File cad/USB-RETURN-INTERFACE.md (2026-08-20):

# Dual 180-degree USB return interface v0.1

## Available sources

Two project references already implement the mechanism:

- NexGen PRO V2 `pro-v2-usb-cover-multi-material.3mf`, raw envelope
  12.65 × 70.35 × 27.93 mm;
- NexGen Redux `redux-optional-usb-cover.3mf`, raw envelope
  12.65 × 70.35 × 32.58 mm.

The selected seller describes 180-degree USB couplers for confined spaces,
claims USB transfer up to 10 Gbit/s and 3 A, and lists several A-D variants.
The unstructured dimension list contains values from 24 to 32 mm without a
reliable variant-to-axis mapping.

## Project envelope

Until the delivered parts can be checked, each coupler receives a conservative
32 × 30 × 29 mm equipment envelope plus 1.0 mm clearance per side. Two couplers
are arranged under one NexGen-style protective hood.

The fixed chassis interface is based on the 70.35 mm reference-cover length.
The coupler-contact insert remains a small replaceable part. If the delivered A
or D variant differs, only that insert changes; the hood, rear panel, and case
do not.

Seller speed/current values are treated as claims, not verified electrical
ratings. The seller's stated manual-measurement error is too ambiguous for a
final press fit, so the first insert remains a fit-check part.

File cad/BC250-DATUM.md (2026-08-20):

# BC-250 mechanical datum v0.1

## Source handling

The locally supplied Printables 1341336 package contains STEP, STL, and a
two-page PDF. Its Standard Digital File License prohibits redistribution,
hosting, and derivatives. None of those files is committed to this repository,
and production CAD does not import or link the restricted geometry.

The model is used only as a local dimensional cross-check. Publishable geometry
is constructed independently from factual dimensions and the already supplied
Public Domain AN600 and MK7 adapter models.

## Locally verified factual envelope

The supplied assembly contains six named solids: board, two mount plates,
radiator, memory radiator, and power adapter.

| Item | Envelope |
|---|---:|
| Bare PCB | 308.0 × 144.3 × 1.6 mm |
| Complete supplied stock assembly | 341.55 × 144.3 × 32.1 mm |

The 341.55 mm length must not define the JF13K case. It includes stock cooling
and mounting parts that are removed or replaced. The power-adapter projection
still requires a dedicated keepout check at the rear of the final carrier.

## Open-reference cross-check

The Public Domain AN600 and MK7 adapters both show an outer 96 × 96 mm hole
square. Their inner cooler-bar patterns differ, so only the outer square is a
strong candidate for the BC-250-side interface. No JF13K hole is frozen until
the actual Intel bars or a physical fit-check confirm it.

## Implemented consequence

`board-spine-v0.1.scad` replaces the former generic horizontal tray study:

- real bare-PCB envelope: 308.0 × 144.3 × 1.6 mm;
- vertical open-centre perimeter spine;
- 0.40 mm provisional pocket clearance per edge;
- split into two printable 168 × 152.3 × 8 mm nominal sections;
- eight transverse M4 chassis points;
- open backplate and rear-component airflow area.

PCB retention clamps remain intentionally unfinished. Their safe positions
depend on a real-board edge-component keepout inspection.

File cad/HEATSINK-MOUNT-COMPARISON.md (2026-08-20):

# BC-250 heatsink mount comparison

## Compared models

| Property | DeepCool AN600 adapter | Sean MK7 mount |
|---|---:|---:|
| Source model | Printables 1707972 | Printables 1217021 |
| Intended cooler | DeepCool AN600 Intel bars | PCCOOLER RZ620 Intel clip bracket |
| STL envelope | 105 × 105 × 8 mm | 105.56 × 104.39 × 8 mm |
| STL volume | 20,382 mm³ | 36,497 mm³ |
| Mesh | 1 closed part, 17,868 facets | 1 closed part, 9,016 facets |
| Author fastener note | 4× M3×12, 4× M3×20, 8× M3 nuts | M4 from below, self-tapped or through with top nuts; mixes cooler and stock hardware |
| License in supplied PDF | Public Domain | Public Domain |

## Conclusion for this case

The MK7 STL is not a revised JF13K mount and must not replace the AN600 adapter
unchanged. It is designed around the much taller PCCOOLER RZ620 and a different
Intel clip system. Its value is that it is a second, independent model of the
same BC-250 heatsink area with an almost identical 105 mm square outer envelope.

The following features should be carried into the project fit-check:

- use the MK7 underside as a second reference for the BC-250 stock-heatsink
  footprint and obstruction relief;
- compare both models' board-side contact surfaces and hole centres before
  freezing the JF13K adapter;
- test M3 and M4 strategies rather than assuming the AN600 M3 hardware is the
  only workable solution;
- keep the adapter separate from the structural JF13K transport supports: the
  adapter controls APU clamping while the chassis supports the 895 g radiator.

No hole coordinates are copied into production CAD yet. The two source STLs do
not prove that JF13K's Intel bars match either model, and the real assembled
cooler must still be measured.

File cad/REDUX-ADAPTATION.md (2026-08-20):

# NexGen3D REDUX — delta review against PRO V2

Source: [Printables model 1649679](https://www.printables.com/model/1649679-nexgen3d-diy-steam-machine-redux-edition), archive downloaded 2026-08-20.

## Correction

Redux does not introduce the project's USB return, rotatable illuminated button, replaceable faceplates, vertical stand, or modular PSU strategy. Those mechanisms were already present in the previously supplied NexGen PRO V2 archive and were already project requirements.

PRO V2 already contains:

- `Case/pro-v2-usb-cover-multi-material.3mf` and a requirement for two black 180-degree USB adapters;
- a three-body rotatable button: mounting plate, translucent rear section, and separate cap;
- separate server PSU, FlexATX/FSP500, and Mean Well LOP mounts;
- replaceable faceplates and access panels;
- horizontal feet and a vertical stand.

## Actual Redux value

Redux remains useful only as a later revision comparison:

- `blank-button.step` gives an editable starting point for checking the future Bazzite cap;
- V4.2.1 documents refined snap tabs and a revised two-part button-cover implementation;
- split-cover joiners provide another way to fit large panels on 220 mm beds;
- the rear storage variants and Orico caddy show a complete receiver/caddy relationship;
- current rear-case variants provide a newer example of one chassis accepting PSU-specific brackets;
- additional cable-tie locations and the rear clamping brace are useful engineering references.

These are refinements, not new project requirements. Nyacom remains the exterior reference and PRO V2 remains the primary source for service mechanisms.

## Measured comparison data

- Redux optional USB cover raw envelope: approximately 12.65 × 70.35 × 32.58 mm.
- Redux server PSU mount raw envelope: approximately 110 × 21.50 × 46.34 mm.
- Redux V4.2.1 blank button is available as editable STEP.
- Redux reference BOM uses 16 M3 inserts described as `M3 × 3.5 × 4.6 × 6` and 16 M3×10 flat-head socket screws. These quantities are not transferred to our BOM.

No Redux mesh is currently used in a project release part.

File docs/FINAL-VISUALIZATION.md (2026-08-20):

# Final model rendering and viewing plan

The project will provide three different representations because one file format cannot correctly serve engineering, printing, and presentation at the same time.

## 1. Engineering assembly

- Source: `cad/final-assembly.scad` or its final equivalent.
- Purpose: dimensional inspection, component visibility toggles, section views, and regeneration after parameter changes.
- Viewer: OpenSCAD, already installed on the development machine.

## 2. Printable parts

- Source: individual STL/3MF files under `cad/exports/`.
- Purpose: slicing, print orientation, support inspection, and per-part replacement.
- Viewer: OrcaSlicer or PrusaSlicer.
- Parts must not be forcibly merged merely to create one assembly file.

## 3. Presentation assembly

- Source scene: `visualization/bc250-case.blend`.
- Portable model: `visualization/bc250-case.glb`.
- Purpose: rotate and inspect the completed enclosure with colours, materials, panels, supports, button, and internal components in their assembled positions.
- Viewer: Blender or any offline/WebGL viewer supporting GLB.

## Required final views

- horizontal three-quarter front;
- horizontal rear and connector view;
- vertical three-quarter front;
- intake-panel close-up;
- front button and USB cassette close-up;
- rear Cisco and FlexATX variants;
- panels removed, showing tray, PSU, SSD, and ESP32;
- exploded assembly view;
- optional 360-degree turntable animation.

## Proposed workflow

1. Export each validated part individually from OpenSCAD.
2. Import parts into Blender without merging them.
3. Apply saved transforms from an assembly manifest.
4. Assign black body, coloured end rings, accent stripe, translucent button light pipe, metal PSU, and PCB materials.
5. Export the assembled scene as GLB.
6. Render still images and optional turntable animation.
7. Verify that the GLB opens independently and that every printable file remains available separately.

This work should begin only after the external geometry and major component locations are stable; otherwise visual transforms and material assignments would need to be repeatedly rebuilt.

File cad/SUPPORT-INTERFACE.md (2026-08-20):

# Common support interface v0.1

The common chassis remains identical in horizontal and vertical use. Orientation is selected by replacing only the external support set.

## Fasteners

- four M4 countersunk screws;
- 4.5 mm printed clearance holes;
- 8.5 mm maximum countersunk head diameter;
- threaded inserts or captive nuts belong to the chassis-side interface and are not yet frozen;
- all coordinates remain provisional until the final chassis wall construction is selected.

## Horizontal set

Two identical 127 × 28 × 8 mm transverse skids. Each skid has two chassis screws on the corrected 99 mm transverse pitch and two 12 × 1.5 mm recesses for optional rubber pads. The parts fit even a small printer and can be replaced independently.

Four reinforced bosses are integrated into the chassis floor at X=36/294 mm and Y=28/127 mm. M4 screws pass through the skids into provisional 5.6 mm heat-set-insert pilots. Final pilot diameter must follow the selected insert manufacturer's recommendation and a material coupon.

## Vertical set

Two identical 230 × 34 × 23 mm transverse feet. A 156 mm cradle accepts the 155 mm narrow side with 0.5 mm nominal clearance per side. Each foot extends 37 mm beyond each side of the chassis, giving a 230 mm anti-tip footprint without creating one oversized printed base.

## Status

These are functional prototype parts, not final production geometry. Before printing, verify the actual wall thickness, insert type, screw-head dimensions, and whether the standing end needs additional retention against lifting.

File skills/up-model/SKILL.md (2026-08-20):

---
name: up-model
description: Audit BC-250 visualization models against CAD sources and refresh only derived browser STL assets. Use for /up-model, $up-model, model synchronization, or viewer/CAD mismatch checks in this repository.
---

# Update visualization models

Run `tools/up-model` from the repository root.

Treat `cad/` and `cad-visualization/` as strictly read-only. Update only derived files under `visualization/assets/`. If a required source is absent, report its exact path and stop; do not fabricate a replacement.

After a successful update, verify that the viewer defaults to the horizontal rear cover and provide the local viewer link. Use `tools/up-model --check` for an audit without changes.

For layout validation, also enforce the mandatory interface rules in
`DESIGN-BRIEF.md`: no unintended geometry outside the enclosure envelope,
exact cover-to-seat and cutout correspondence, no unsupported/floating parts,
and explicit structural and airflow consideration for every occupied internal
volume. Report violations instead of masking them with viewer-only geometry.

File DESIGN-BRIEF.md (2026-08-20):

# BC-250 + JF13K case — рабочее техническое задание

Статус: предварительное; геометрия не считается подтверждённой до сверки CAD и независимых измерений.

## Архитектура

Корпус строится вокруг общего модуля `BC-250 + адаптер + JIUSHARK JF13K`.

Две независимые оси модульности:

1. Сменная нижняя/задняя опорная деталь:
   - горизонтальная установка;
   - вертикальная установка.
2. Сменная кассета блока питания:
   - Cisco UCSC-PSU-650W V02;
   - будущий FlexATX.

Смена ориентации или PSU не должна требовать перепечатки общего chassis, панели intake JF13K и лицевой панели.

## Подтверждённое оборудование

- Плата: AMD/ASRock BC-250, разблокированная конфигурация 40 CU / 8 CPU cores.
- Кулер: JIUSHARK JF13K Diamond.
- Начальный PSU: Cisco UCSC-PSU-650W V02.
- Идентификация PSU по открытым источникам: Delta DPS-650AB-2 A, Cisco P/N 341-0490-02, 650 W, 12 V, 80 Plus Platinum.
- Принтер пока не выбран; возможна заказная печать.
- Основной накопитель на первом этапе: M.2.

## Пользовательские узлы

- Предусмотреть съёмное крепление минимум одного стандартного 2,5″ SATA-устройства; оно не обязано устанавливаться в базовой сборке.
- Крепление 2,5″ не должно перекрывать замену M.2, airflow обратной стороны BC-250 или обслуживание PSU.

### Обязательная проверка компоновки и интерфейсов

Эти требования применяются ко всем существующим и новым деталям корпуса,
кассетам, крышкам, креплениям и внутренним компонентам:

- Ни одна часть корпуса, посадочного места, направляющей или внутреннего шасси
  не должна выходить за внешний envelope корпуса, кроме явно согласованных
  наружных органов управления, разъёмов, ножек и декоративных элементов.
- Посадочные места, проёмы, вырезы, магниты и крепёжные оси должны точно
  соответствовать сопрягаемой крышке. В крышке запрещены неподтверждённые
  отверстия, вентиляционные прорези и технологические вырезы.
- Каждый элемент должен иметь явную опору, крепление и путь передачи нагрузки.
  Детали без физического контакта с посадочным местом или крепежом считаются
  висящими в воздухе и блокируют выпуск модели.
- Защёлка считается спроектированной только вместе с ответным уступом. В
  сечении проверяются направление установки, траектория прогиба, зацеп,
  освобождение и печатные зазоры. Рычаг и ответный карман должны следовать
  нормали к локальной поверхности корпуса, включая фаски и наклонные стенки.
- При проектировании внутренних объёмов необходимо проверить толщину стенок,
  жёсткость, локальные усиления, направление печати, доступ к крепежу,
  обслуживание, кабельные радиусы и поток воздуха. Освобождение геометрического
  объёма само по себе не считается достаточной компоновкой.
- Перед экспортом должны быть проверены общий внешний envelope, пересечения,
  зазоры каждой пары сопрягаемых деталей и непрерывность несущей геометрии.
- Лицевая панель: кнопка питания и сменный модуль USB-хаба.
- USB-хаб: минимум один USB-A data и один USB-C data; питание и data-порты должны быть явно различимы.
- Корпус хаба не интегрировать намертво: использовать сменную кассету/faceplate под конкретную серийную модель.
- По принятой архитектуре NexGen PRO V2 использовать два чёрных 180° USB 3.0 адаптера для возврата задних USB-портов внутрь корпуса; предусмотреть защитный козырёк, фиксацию и разгрузку разъёмов. Точную ориентацию подтвердить по реальным адаптерам.
- Внешняя кнопка подключается к отдельному контроллеру на основе проекта `zloymalefic/BC-250-PC-Remote-Control`.
- Предусмотреть отдельный съёмный electronics tray для комбинированной платы ESP32-WROOM + 2 relay, разъёмов и сервисного запаса проводов.
- Не размещать ESP32 в металлически экранированном кармане или вплотную к PSU; зона антенны должна быть обращена к пластиковой панели и удалена от силовых проводов.
- Electronics tray должен оставлять доступ к USB ESP32 для первичной прошивки и восстановления, даже если штатно используются OTA-обновления.

## Предварительные ограничения печати

- Желательный envelope отдельной детали: не более 250 × 250 × 250 мм.
- Ограничение предварительное и может быть пересмотрено после выбора конструкции.
- Финальный материал: PETG-CF/PETG-GF или ASA/ABS; обычный PLA не является целевым материалом.

## Финальная визуализация и просмотр

Финальная поставка должна включать не только отдельные печатные STL/3MF, но и собранную визуальную модель корпуса:

- мастер-сборка OpenSCAD с раздельно включаемыми компонентами;
- Blender-сцена с назначенными цветами/материалами Nyacom-style корпуса;
- переносимый `GLB` для свободного вращения модели без CAD-софта;
- набор рендеров horizontal/vertical, front/rear и со снятыми сервисными панелями;
- exploded-view, показывающий последовательность сборки;
- при возможности короткий turntable-рендер 360°;
- отдельный набор STL/3MF остаётся источником для слайсера и не объединяется в неманифолдную «монолитную» сетку.

Рекомендуемый просмотр: Blender для полной сцены и рендера, любой локальный/WebGL GLB viewer для быстрого осмотра, OrcaSlicer/PrusaSlicer для проверки отдельных печатных деталей.

## Функциональные интерфейсы

### Общий chassis ↔ опора ориентации

- единый рисунок крепёжных точек для horizontal и vertical вариантов;
- нагрузка JF13K замыкается через chassis;
- опора не передаёт транспортные нагрузки через PCB;
- обе опоры сохраняют intake JF13K, exhaust и канал под обратной стороной платы;
- ножки/подставка должны быть сменными без разборки кулера.

### Общий chassis ↔ кассета PSU

- единый посадочный интерфейс;
- весь PSU, его кассета, защёлка и силовой адаптер располагаются внутри внешнего envelope корпуса;
- наружу не выступают PSU или его крепление; допустима только задняя панель заподлицо с цветной торцевой рамкой;
- Cisco и FlexATX используют разные внутренние адаптеры на одном универсальном шасси;
- независимый забор воздуха PSU, если это допускает компоновка;
- исключить подачу основного горячего выхлопа JF13K на вход PSU;
- предусмотреть фиксацию кабеля питания BC-250 и разгрузку мест пайки/переходной платы PSU;
- кассета Cisco не должна требовать необратимой модификации корпуса PSU.

### Съёмные внешние панели

- основной способ фиксации - печатные защёлки/крючки по принципу NexGen PRO V2;
- штатное снятие панелей выполняется без отвёртки;
- болты не должны быть видимы на внешних декоративных панелях;
- страховочные винты допустимы только внутри корпуса или в несущих узлах, которые не снимаются при обычном обслуживании.

### Кнопка питания

- использовать трёхдетальную архитектуру NexGen PRO V2: монтажная пластина, светопроводящая задняя часть и отдельная нажимная эмблема;
- кнопочный модуль должен выниматься и поворачиваться на 90 градусов при смене ориентации корпуса;
- электрический переключатель и окончательная эмблема остаются сменными.
- предусмотреть отдельную поворотную крышку кнопки с логотипом Bazzite; базовая механика остаётся NexGen PRO V2, а Redux `blank-button.step` используется только как более поздняя редактируемая заготовка для сверки.

## Требующие подтверждения параметры

- точный контур, отверстия, I/O и зоны компонентов BC-250;
- геометрия JF13K и его штатного крепления;
- совместимость адаптера AN600 с JF13K;
- envelope собранного узла, включая винты, отвёртку и кабели;
- посадка универсального server-PSU адаптера NexGen во внутренний интерфейс
  110 × 46,34 мм; отдельный обмер корпуса Cisco PSU не требуется;
- схема безопасного запуска и силового подключения Cisco PSU;
- ориентация I/O и кнопки питания в horizontal/vertical режимах;
- требования к SSD, Wi-Fi/антеннам, фронтальным USB и другим дополнительным узлам.
- точная модель USB-хаба и способ подключения к одному из задних USB-портов BC-250;
- комбинированная плата контроллера: выбран вариант `DC5-60V 2 channel`, ESP32-WROOM, ориентировочный envelope платы 60 × 60 мм по карточке товара; точный контур и межосевые расстояния четырёх отверстий требуют измерения;
- распиновка UART-разъёма и GPIO встроенных реле комбинированной платы;
- разъёмы и безопасная трасса проводов от контроллера к TPMS1, кнопке BC-250 и PSU.

## Предварительный вывод по адаптеру AN600

- Полученная модель имеет размеры 105 × 105 × 8 мм и использует четыре внешних отверстия BC-250 плюс четыре внутренних точки под Intel-планки AN600.
- JF13K комплектуется собственными Intel LGA1700 mounting bars и крепится винтами со стороны backplate.
- Сообщество подтверждает установку JF13K через LGA1700-to-BC250 adapter, но упоминает снятие штатных чёрных элементов и добавление четырёх проставок 1–2 мм.
- Поэтому совместимость считается условно подтверждённой по принципу интерфейса, но не подтверждённой для неизменённого STL и штатного набора винтов.
- До fit-check необходимо сверить положение отверстий JF13K, требуемую высоту проставок, контакт холодной пластины и диапазон пружинного прижима.

## Ближайший контрольный результат

Первый технический отчёт должен сравнить 2–3 компоновки, показать airflow, приблизительные внешние размеры, риски и перечень новых/переиспользуемых деталей. До этого финальный корпус не моделируется.

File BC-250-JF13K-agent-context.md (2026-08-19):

# BC-250 + JF13K — контекст проекта для агента

## Цель проекта

Спроектировать компактный, тихий и пригодный для 3D-печати корпус класса Steam Machine для мощной разблокированной платы AMD BC-250:

- 40 CU GPU;
- 8 CPU cores;
- повышенные относительно штатных частоты и напряжения;
- основной сценарий — игры;
- низкий шум под игровой нагрузкой важнее минимальной цены.

Для дальнейшей работы считать, что BC-250 и JIUSHARK JF13K Diamond уже куплены. Не тратить время на поиск, покупку или подбор более дешёвого кулера, если пользователь отдельно не вернётся к этому вопросу.

Проектировать нужно не абстрактный корпус для BC-250, а систему вокруг реальной сборки:

`BC-250 PCB + крепёжный адаптер + установленный JF13K + PSU`

## Основное охлаждение: JIUSHARK JF13K Diamond

JF13K — большой низкопрофильный top-down кулер, который задаёт геометрию будущего корпуса.

Ориентировочные характеристики, которые необходимо перепроверить по конкретной ревизии и реальному экземпляру:

- радиатор около 241 × 121 мм;
- общая высота около 92 мм;
- 7 тепловых трубок;
- 2 × 120 × 15 мм вентилятора;
- масса около 895 г.

Почему выбран JF13K:

- большая площадь радиатора;
- два 120-мм вентилятора вместо одного высокооборотистого;
- потенциально более низкий шум;
- top-down airflow охлаждает не только APU, но и компоненты вокруг него;
- кулер может одновременно быть основным intake корпуса.

JF13K уже был физически установлен другим пользователем на BC-250. По имеющимся фотографиям жизнеспособность компоновки подтверждена: кулер расположен параллельно PCB, используется четырёхточечное подпружиненное крепление, I/O остаётся доступным, а кабели питания уходят от края платы вбок. Не считать нависание кулера над PCB проблемой доступа к кабелям без фактического подтверждения.

При проектировании использовать реальные размеры собранного модуля, а не складывать номинальные размеры компонентов на глаз. Особое внимание уделить нагрузке почти 900-граммового кулера на PCB, прижиму APU, backplate и безопасной транспортировке корпуса.

## Существующий адаптер AN600

Первый кандидат для крепления — [DeepCool AN600 adapter for AMD BC-250](https://www.printables.com/model/1707972-deepcool-an600-adapter-for-amd-bc-250).

Адаптер сделан для DeepCool AN600, а не специально для JF13K. Геометрия показанной в сообществе установки JF13K похожа на это решение, но нельзя считать без проверки, что использован неизменённый STL.

До разработки собственного крепления агент должен:

1. Скачать все доступные файлы адаптера.
2. Найти STEP, 3MF или другие редактируемые исходники; не ограничиваться STL.
3. Сверить межосевые расстояния, высоту стоек, положение контактной площадки, ориентацию теплотрубок и доступный ход пружинных винтов.
4. Проверить совместимость с крепёжной системой JF13K.
5. Определить, можно ли использовать адаптер без изменений или нужна локальная модификация.
6. Проверить схему backplate, распределение нагрузки и электрические зазоры.

Не проектировать крепление с нуля, пока этот адаптер не изучен.

## Принцип airflow

Предпочтительный путь воздуха:

`холодный воздух снаружи → 2×120 мм вентилятора JF13K → радиатор → лицевая сторона BC-250 → контролируемые зоны exhaust`

Основные правила:

- панель напротив вентиляторов JF13K должна иметь большую открытую площадь;
- ориентировочный зазор между вентиляторами и mesh — 5–10 мм, но его нужно проверить тестом на шум и сопротивление;
- не добавлять корпусные вентиляторы «на всякий случай»;
- первый прототип должен проверить, достаточно ли двух вентиляторов JF13K для всего корпуса;
- не исходить из принципа «больше отверстий везде = лучше» — нужен направленный и предсказуемый поток;
- PSU не должен перекрывать intake или получать весь горячий выхлоп JF13K.

Отдельная зона риска — обратная сторона BC-250, backplate и память. JF13K напрямую их не охлаждает. Предусмотреть:

- воздушный зазор и канал под PCB;
- возможность направить часть потока от JF13K под плату;
- посадочное место под тихий 80/92-мм вентилятор как резерв.

Дополнительный вентилятор устанавливать только если измерения покажут необходимость. Важно проверить не только температуру APU, но и косвенные признаки перегрева памяти/обратной стороны платы.

## Референс 1: Nyacom

[Nyacom's AMD BC-250 Industrial Style Case for FlexATX](https://www.printables.com/model/1737913-nyacoms-amd-bc-250-industrial-style-case-for-flexa)

Использовать как геометрический и дизайнерский референс:

- компактная компоновка BC-250 + FlexATX;
- простой chassis;
- industrial / Steam Machine эстетика;
- съёмные или магнитные панели;
- удобная базовая ориентация компонентов.

Оригинальная конструкция рассчитана прежде всего на штатное охлаждение BC-250; JF13K в неё напрямую не помещается. Не масштабировать весь корпус пропорционально и не пытаться механически «растянуть» STL. Нужно понять, какие решения Nyacom сохраняют компактность, а какие придётся заменить.

## Референс 2: NexGen3D PRO V2

[NexGen3D DIY Steam Machine PRO V2 — Liquid Cooled BC-250](https://www.printables.com/model/1793043-nexgen3d-diy-steam-machine-pro-v2-liquid-cooled-bc)

Это главный инженерный референс. Пользователь уже применял корпус этого автора в предыдущем проекте и ценит качество конструкции, понятную последовательность сборки и подробные инструкции.

Изучить и по возможности перенести принципы:

- модульный chassis из отдельных печатных деталей;
- съёмные боковые панели и отдельная панель доступа к кабелям;
- сменные faceplates;
- модульные крепления PSU;
- поддержка FlexATX, Mean Well LOP и server PSU в общей архитектуре;
- контролируемый airflow;
- удобное обслуживание без полной разборки;
- практические допуски и ориентация деталей для 3D-печати;
- вертикальная установка, если она совместима с тяжёлым JF13K;
- подробная финальная инструкция и перечень крепежа.

PRO V2 рассчитан на жидкостное охлаждение/AIO и крупнее, чем требуется для JF13K. Не переделывать его буквально заменой AIO на JF13K. Использовать его архитектуру, модульность и документацию как образец.

## Предпочтительное направление конструкции

Рабочая концепция — собственный гибрид, а не ремикс одного STL:

- от Nyacom: компактность, общая компоновочная логика и внешний вид;
- от NexGen3D: модульность, доступ к узлам, PSU-модули, airflow и качество документации;
- от существующей установки JF13K: реальная геометрия модуля `BC-250 + adapter + JF13K`.

Корпус желательно разбить минимум на:

- основной chassis;
- вентиляционную панель JF13K;
- крепление PSU;
- front panel / faceplate;
- access panel;
- ножки или вертикальную подставку;
- при необходимости отдельные I/O-элементы и канал охлаждения backplate.

Изменение одной функциональной зоны не должно требовать перепечатки всего корпуса.

## PSU

Базовый и приоритетный вариант — качественный FlexATX достаточной мощности для разблокированной BC-250. Рабочий ориентир — класс 400–500 Вт, но окончательный выбор должен опираться на измеренное потребление конкретной платы и запас по 12 В.

Желательно оценить модульное крепление по мотивам NexGen3D для:

- FlexATX;
- Mean Well LOP;
- совместимого компактного server PSU или другого реального кандидата.

Модульность имеет смысл только если не увеличивает корпус и сложность непропорционально пользе. Если возникает конфликт, приоритет у простой и компактной версии под FlexATX. Нужно также проверить шум вентилятора PSU и возможность его независимого забора холодного воздуха.

## Материалы и пригодность для печати

Финальную версию не ориентировать на обычный PLA из-за температуры и длительной механической нагрузки.

Кандидаты:

- PETG;
- PETG-CF / PETG-GF;
- ASA или ABS при подходящих условиях печати.

Материал и конструкцию выбирать с учётом температуры, ползучести пластика, массы JF13K, резьбовых вставок, обслуживания и повторяемости печати. Для первого fit-check допустим дешёвый прототипный материал, но не как подтверждение долговечности финальной конструкции.

## Приоритеты проекта

В порядке важности:

1. Низкий шум под реальной игровой нагрузкой.
2. Достаточное охлаждение разблокированной BC-250 40 CU / 8C.
3. Безопасное и жёсткое крепление тяжёлого JF13K.
4. Компактность.
5. Контролируемый airflow с минимальным числом вентиляторов.
6. Простая сборка, обслуживание и доступ к кабелям.
7. Хорошая пригодность для 3D-печати.
8. Модульность только там, где она даёт практическую пользу.
9. Аккуратный industrial / Steam Machine внешний вид.
10. Подробная инструкция финальной сборки в стиле NexGen3D.

## Первые задачи агента

Не начинать с рисования финального корпуса.

1. Скачать и изучить все доступные файлы Nyacom.
2. Скачать и изучить все доступные файлы NexGen3D PRO V2 и связанные инструкции.
3. Скачать и изучить адаптер AN600 → BC-250.
4. Составить список доступных исходных форматов: STEP, 3MF, CAD, STL, чертежи и BOM.
5. Найти или измерить точную геометрию BC-250: контур PCB, отверстия, I/O, силовые разъёмы, зоны компонентов и backplate.
6. Найти или измерить точную геометрию конкретного JF13K и его крепежа.
7. Проверить совместимость JF13K с существующим AN600-адаптером; предложить минимальные изменения при необходимости.
8. Получить габаритный envelope реальной сборки `BC-250 + adapter + JF13K`, включая кабели, ход отвёртки и монтажные зазоры.
9. Сравнить компоновку, сервисный доступ и airflow Nyacom и NexGen3D.
10. Определить, какие детали или принципы можно переиспользовать законно и технически, а что лучше спроектировать заново.
11. Предложить 2–3 рациональные компоновки с приблизительными внешними размерами, схемой airflow, положением PSU и оценкой печатных деталей.
12. Для каждой компоновки перечислить риски: изгиб PCB, горячий воздух PSU, охлаждение backplate, рециркуляция, шум решётки, доступ к I/O и сложность сборки.
13. Выбрать архитектуру только после сравнения вариантов и проверки размеров.
14. Затем изготовить отдельно крепление/адаптер, выполнить open-bench тесты температуры и шума и только после этого переходить к прототипу корпуса.

## Критерии первого технического отчёта

Первый отчёт агента должен содержать:

- таблицу подтверждённых размеров и источников;
- вывод о совместимости адаптера AN600 с JF13K;
- схемы 2–3 компоновок и приблизительные внешние размеры;
- предполагаемый airflow каждой компоновки;
- перечень переиспользуемых и новых деталей;
- список неизвестных параметров, которые требуют физического измерения;
- рекомендацию одной архитектуры с объяснением компромиссов;
- план open-bench испытаний: нагрузка, длительность, температуры, обороты и шум.

Не выдавать неподтверждённые размеры или совместимость за установленные факты. Все решения корпуса должны опираться на реальные файлы или измерения собранного узла.

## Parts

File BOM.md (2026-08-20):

# BC-250 case — BOM и список закупки

Версия: `v0.1`, предварительная  
Конфигурация расчёта: горизонтальный корпус, Cisco UCSC-PSU-650W V02, JIUSHARK JF13K, фронтальный USB-хаб, кассеты SSD и ESP32.

> **Закупка корпуса приостановлена.** Аудит выявил несовместимые и отсутствующие интерфейсы. Количества ниже являются черновыми целевыми позициями, а не разрешением на заказ, пока не выпущен единый сборочный комплект.

Этот документ разделяет позиции на три группы:

- **покупать** — типоразмер уже определён и пригодится независимо от уточнения электроники;
- **опция** — не требуется для базовой сборки;
- **не покупать пока** — количество предусмотрено, но геометрия или электрическая спецификация ещё не подтверждены.

`Артикул проекта` — стабильный внутренний идентификатор. В колонке `Спецификация` указан стандарт или размер, по которому можно искать товар у любого продавца.

## Крепёж и механические расходники

| Артикул проекта | Спецификация для поиска | В сборку | Купить | Статус | Назначение |
|---|---|---:|---:|---|---|
| `BC250-HW-M3X30-4762` | винт M3×30, ISO 4762 / DIN 912 | 0 | 0 | не покупать | продольная стяжка признана недоступной в собранном корпусе |
| `BC250-HW-M3-NYL-985` | гайка самоконтрящаяся M3, DIN 985 | 0 | 0 | не покупать | исключена вместе с продольной стяжкой |
| `BC250-HW-M3X08-7380` | винт M3×8, ISO 7380-1, полукруглая головка | 10 | 20 | покупать | плата, кнопка и внутренние кассеты |
| `BC250-HW-M3X04-7380` | винт M3×4, ISO 7380-1 | 4 | 10 | покупать | стандартное крепление 2,5-дюймового SSD |
| `BC250-HW-M3X10-10642` | винт M3×10, ISO 10642 / DIN 7991, потайная головка | 8 | 12 | **не покупать пока** | 4 передняя панель + 4 обычная задняя крышка; длину подтвердить после fit-check |
| `BC250-HW-M3X45-10642` | винт M3×45, ISO 10642 / DIN 7991, потайная головка | 4 | 8 | **не покупать пока** | вертикальная крышка-основание глубиной 44 мм |
| `BC250-HW-M3-INS-46` | латунная термовставка M3, наружный Ø4,6 мм, L=5,7–6 мм | 12 | 20 | **не покупать пока** | резьба платы и сервисных кассет; карманы ещё не заморожены |
| `BC250-HW-M4X12-10642` | винт M4×12, ISO 10642 / DIN 7991, потайная головка | 4 | 8 | покупать | горизонтальные опоры/полозья |
| `BC250-HW-M4-INS-56` | латунная термовставка M4, наружный Ø5,6 мм, L=6 мм | 4 | 10 | **не покупать пока** | общий интерфейс сменной нижней части |
| `BC250-HW-PAD-12X2` | самоклеящаяся резиновая ножка Ø12×2 мм | 4 | 8 | покупать | горизонтальные полозья либо четыре углубления вертикального основания |
| `BC250-HW-PAD-14X2` | самоклеящаяся резиновая ножка Ø14×2 мм | 0 | 0 | не покупать | прежний размер вертикальной опоры заменён общим Ø12 мм |
| `BC250-HW-TIE-100` | кабельная стяжка 100×2,5 мм | 12–20 | 100 | покупать | укладка сигнальных проводов |
| `BC250-HW-TIEBASE-20` | самоклеящаяся площадка под стяжку 20×20 мм | 4–8 | 20 | покупать | временная укладка до финальных печатных клипс |

Две боковые intake-панели и отдельная крышка ESP32 крепятся магнитами. Направляющие и опорные бортики воспринимают сдвиг; магниты работают на отрыв. Передняя и монолитная задняя панели крепятся винтами M3.

## Магниты

| Артикул проекта | Спецификация | В сборку | Купить | Статус |
|---|---|---:|---:|---|
| `BC250-HW-MAG-08X02` | неодимовый диск 8×2 мм, N52, никелированный | 24 | 28 | покупать после проверки кармана |

Раскладка: 16 магнитов для двух боковых грилей и 8 для отдельной крышки ESP32; ещё 4 запасных. Нужен двухкомпонентный эпоксидный клей либо подходящий цианоакрилат для магнита и выбранного пластика. Перед вклейкой отметить полярность: сначала вклеить корпусную сторону, затем установить ответные магниты через тонкую разделительную ленту и вклеить панели.

## Пластик

Предыдущая оценка по разрозненным STL отозвана: эти модели перекрывались, включали непечатные equipment envelopes и не составляли одну сборку. Точный расход будет пересчитан только по проверенному release-комплекту.

| Артикул проекта | Материал | Расчёт модели | Закупочный минимум | Рекомендуется для первой сборки |
|---|---|---:|---:|---:|
| `BC250-MAT-STRUCT-DARK` | PETG или ASA, основной тёмный цвет | отозван | 0 | ждать release BOM |
| `BC250-MAT-ACCENT-YEL` | тот же материал, жёлтый акцент | не рассчитан | 0 | ждать release BOM |
| `BC250-MAT-ACCENT-RED` | тот же материал, красный акцент | не рассчитан | 0 | ждать release BOM |
| `BC250-MAT-BUTTON-CLEAR` | натуральный/прозрачный PETG для световода | не рассчитан | 0 | ждать release BOM |

Для калибровочных образцов достаточно заказать печать самих четырёх STL из `cad/exports/`; покупать полноразмерные катушки только ради них не требуется.

Для тонких направляющих не применять хрупкий CF/GF-наполненный материал без отдельного теста. Безопасный старт — обычный PETG или ASA и обязательная пробная печать кармана магнита.

## Электроника и кабели

| Артикул проекта | Спецификация / ссылка | В сборку | Купить | Статус |
|---|---|---:|---:|---|
| `BC250-EL-HUB-01` | Anker A7516 Ultra Slim 4-Port USB 3.0 Hub, короткий кабель 0,75 ft, корпус 103×30×10 мм; [Anker](https://www.anker.com/uk/products/a7516) | 1 | 1 | текущий базовый вариант NexGen3D; перед заказом проверить именно модель A7516 и короткий кабель |
| `BC250-EL-USBA-ANG-01` | угловой USB-A male-to-female адаптер, [AliExpress 1005005963998184](https://pl.aliexpress.com/item/1005005963998184.html) | 1 | 2 | **не покупать пока** — подтвердить направление угла |
| `BC250-EL-ESP2R-01` | ESP32-WROOM, 2 реле, питание DC 5–60 V, плата около 60×60×22 мм | 1 | 1 | выбранная плата; кассета готова, перед финалом нужны шаг отверстий и стороны разъёмов |
| `BC250-EL-SW16-MOM` | кнопка Ø16 мм, momentary NO, отдельная подсветка | 1 | 2 | **не покупать пока** — сверить ход с печатным толкателем и напряжение LED |
| `BC250-EL-WIRE-SIG` | гибкий многожильный провод 24–26 AWG | ≈2 м | 5 м | покупать | кнопка, реле, сервисные сигналы |
| `BC250-EL-HST-KIT` | термоусадка 2:1, Ø2/3/4/6 мм | ≈0,5 м | набор | покупать | изоляция сигнальных соединений |
| `BC250-EL-SSD7` | SATA SSD/HDD 2,5 дюйма, толщина 7–15 мм | 0–1 | 0–1 | опция; кассета поддерживает стандартный нижний шаг 76,6×61,72 мм |

Силовой жгут Cisco PSU → BC-250 намеренно не внесён как готовая закупочная позиция. До подтверждения распиновки, токов, сечения, типа контактов и способа запуска покупать разъёмы и собирать силовой кабель небезопасно.

## Уже имеющееся или крупные комплектующие

| Артикул проекта | Комплектующий | Количество | Примечание |
|---|---|---:|---|
| `BC250-ASSY-BOARD` | AMD/ASRock BC-250 | 1 | точный контур и I/O ещё сверяются |
| `BC250-ASSY-COOLER` | JIUSHARK JF13K Diamond | 1 | включает два вентилятора 120×15 мм |
| `BC250-ASSY-PSU-CISCO` | Cisco UCSC-PSU-650W V02 / 341-0490-02 | 1 | базовая конфигурация |
| `BC250-ASSY-ADAPTER` | LGA1700-to-BC250 mounting adapter | 1 | проставки 1–2 мм требуют fit-check |

## Перед оформлением заказа

1. Распечатать небольшой образец кармана Ø8,25×2,20 мм и проверить фактическую посадку выбранного магнита; отдельно использовать `cad/exports/fit-calibration-coupon-v0.1.stl` для калибров M3/M4.
2. JF13K и базовый Anker A7516 уже внесены в габаритную сборку. До финальной
   ревизии остаются размеры ESP32-релейной платы и физическая проверка кассеты
   хаба. Cisco PSU использует универсальный адаптер NexGen и отдельного обмера
   корпуса не требует.
3. Проверить выбранные M3/M4 термовставки на отдельном образце; наружный диаметр у разных производителей заметно различается.
4. После выбора сервиса печати получить финальную оценку материала из слайсера; масса выше — инженерная оценка по геометрическому объёму STL.
5. Заморозить ревизию CAD, после чего убрать пометки `не покупать пока` и выпустить BOM `v1.0`.

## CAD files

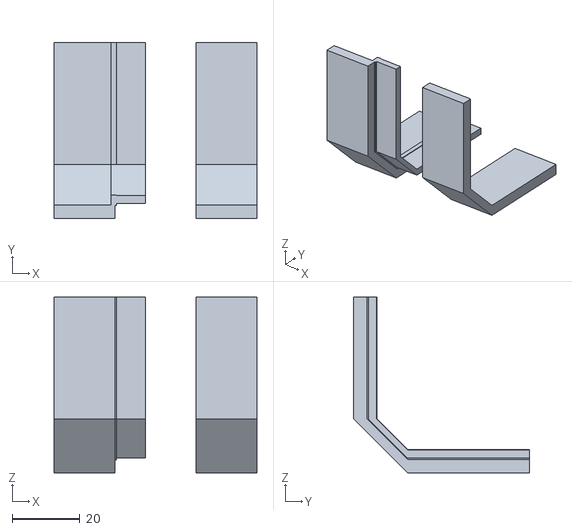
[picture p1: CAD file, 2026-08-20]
cad/exports/chassis-joint-coupon-0.35mm-v0.1.stl
60.0 x 52.0 x 52.0

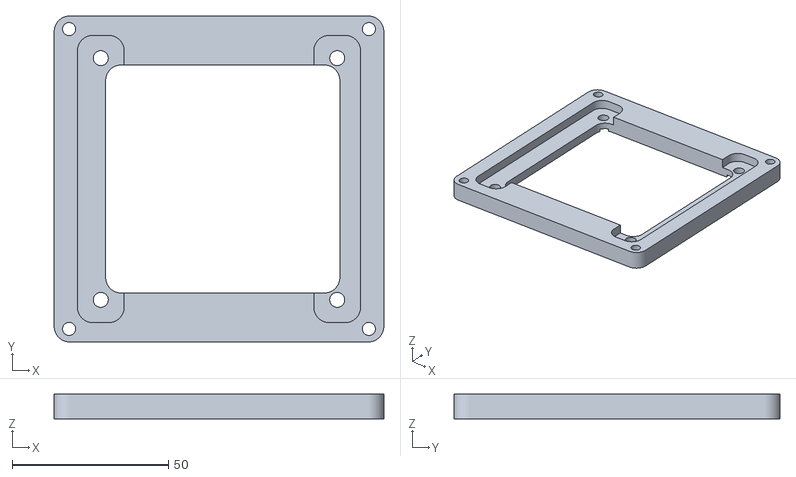
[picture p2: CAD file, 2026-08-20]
references/printables-1217021-heatsink-mount/bc-250-mk7.stl
105.6 x 104.4 x 8.00

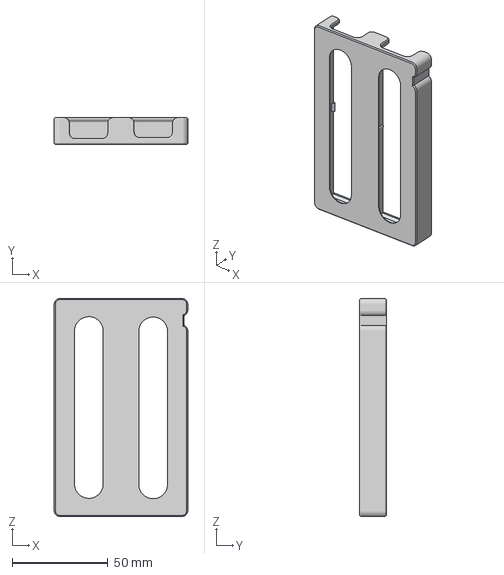
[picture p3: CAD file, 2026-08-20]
references/printables-1649679-nexgen-redux/Case V4.2 - Current Version/redux-orico-usb-drive-bay.3mf
69.8 x 14.0 x 114.0 mm

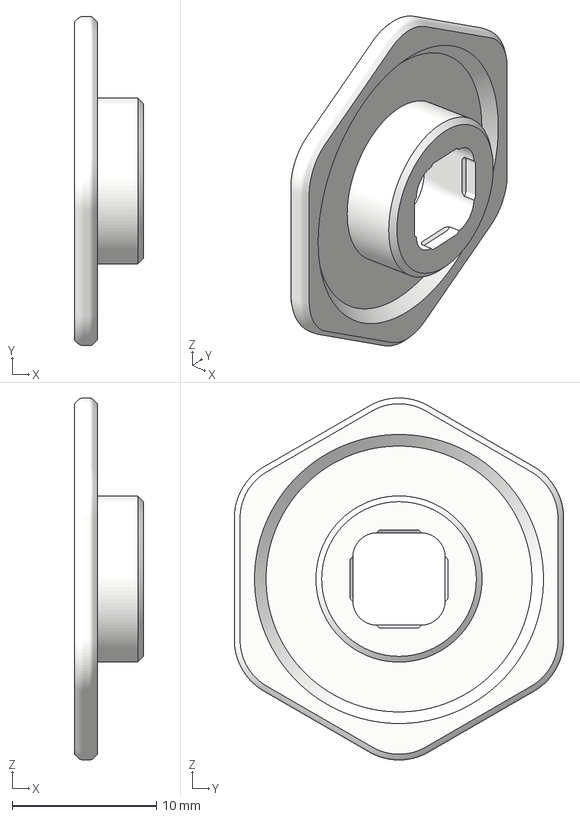
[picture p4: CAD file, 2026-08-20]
references/printables-1649679-nexgen-redux/Face Plates V4.2.1 - Current Version/standard-button-body-for-latching-switch.3mf
4.80 x 22.8 x 25.1 mm

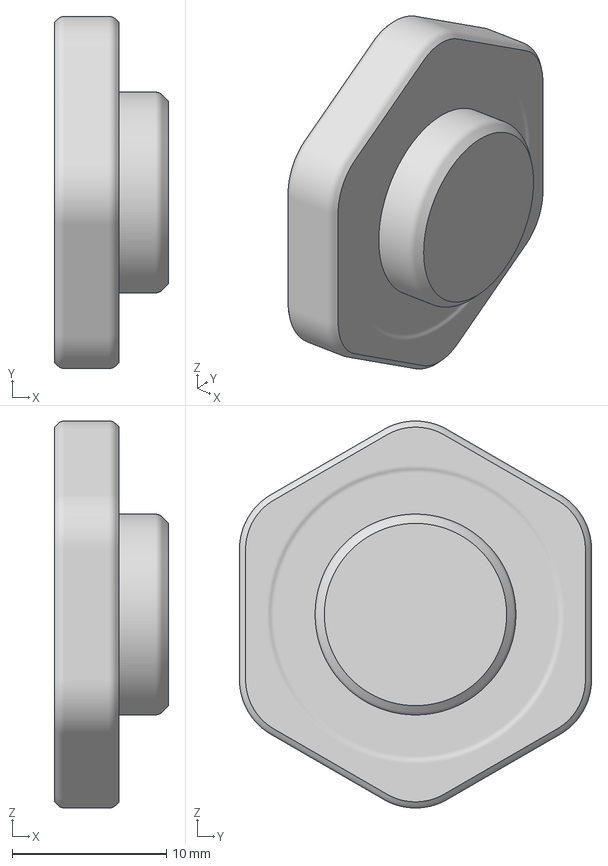
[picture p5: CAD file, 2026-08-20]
references/printables-1649679-nexgen-redux/Face Plates V4.2/display-panel-button-for-generic-latching-switch.3mf
7.40 x 22.8 x 25.1 mm
Accent-1
Accent-2
Accent-3
Blank Button for Generic Latching Switch

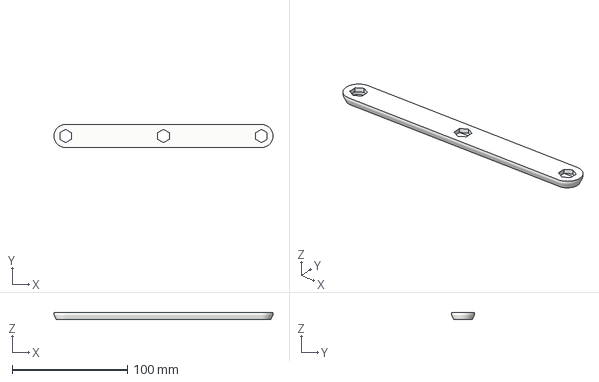
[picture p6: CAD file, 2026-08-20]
references/printables-1649679-nexgen-redux/Fan Mount and Feet V4.2 - Current Version/optional-long-foot-petg.3mf
189.6 x 20.0 x 6.00 mm

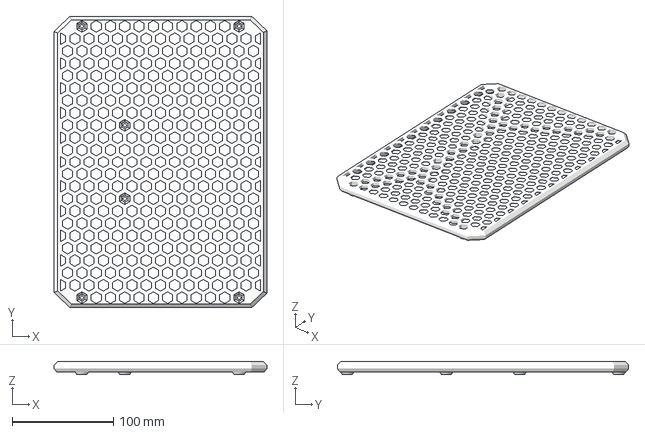
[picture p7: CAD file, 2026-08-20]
references/printables-1649679-nexgen-redux/Hex Covers for 300x300 Beds - Current Version/redux-top-hex-cover.3mf
210.8 x 288.5 x 12.9 mm

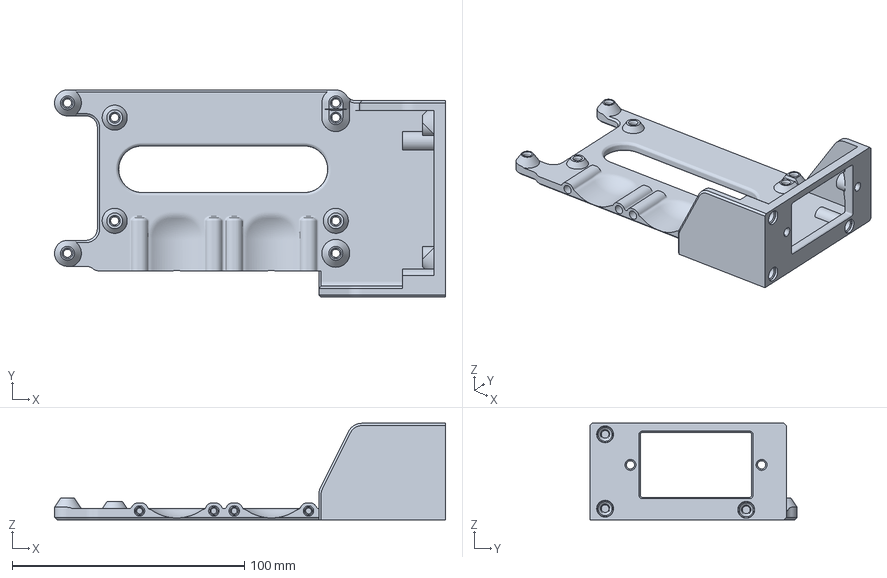
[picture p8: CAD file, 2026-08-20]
references/printables-1649679-nexgen-redux/Optional Parts - Current Version/meanwell-lop-300-400-mount.3mf
168.4 x 89.2 x 41.6 mm

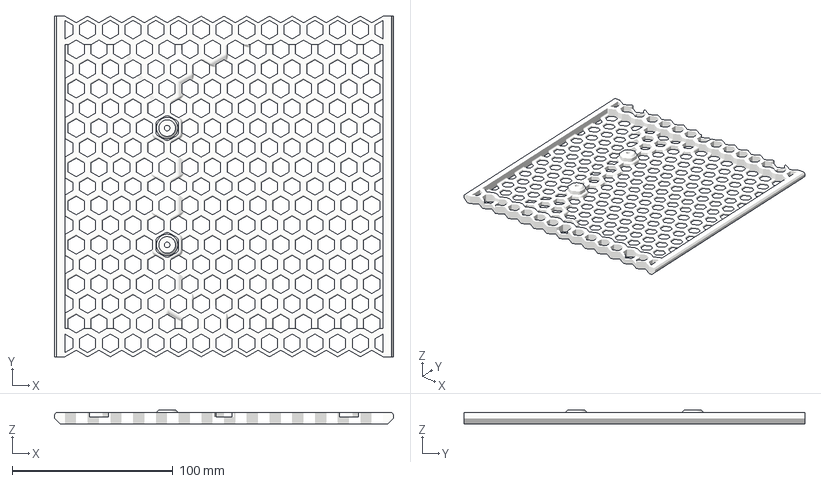
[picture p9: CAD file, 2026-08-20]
references/printables-1649679-nexgen-redux/Split Hex Covers for 220x220mm or Larger/bottom-split-panel-b.3mf
210.8 x 211.8 x 8.90 mm

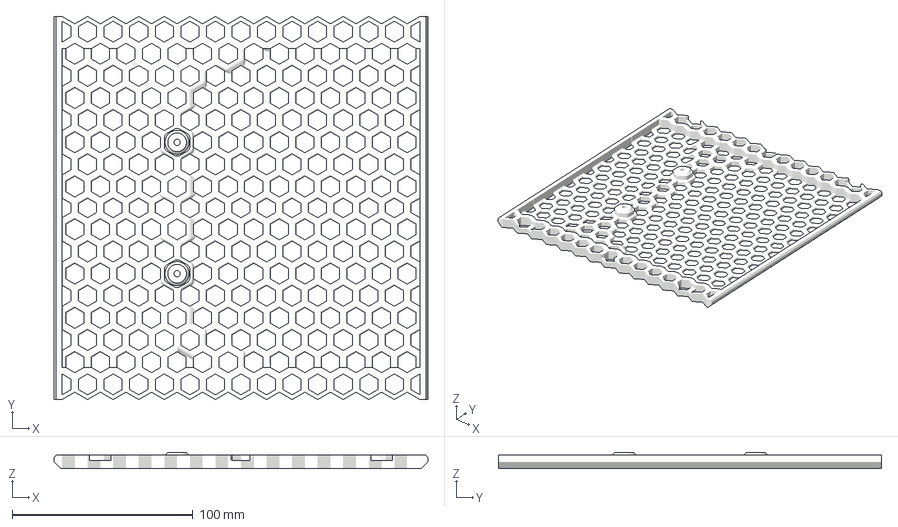
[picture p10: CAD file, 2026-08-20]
references/printables-1649679-nexgen-redux/Split Hex Covers for Odd Ball Prusa Beds (250x210)/prusa-priners-only-bottom-split-panel-b.3mf
206.8 x 211.8 x 8.90 mm

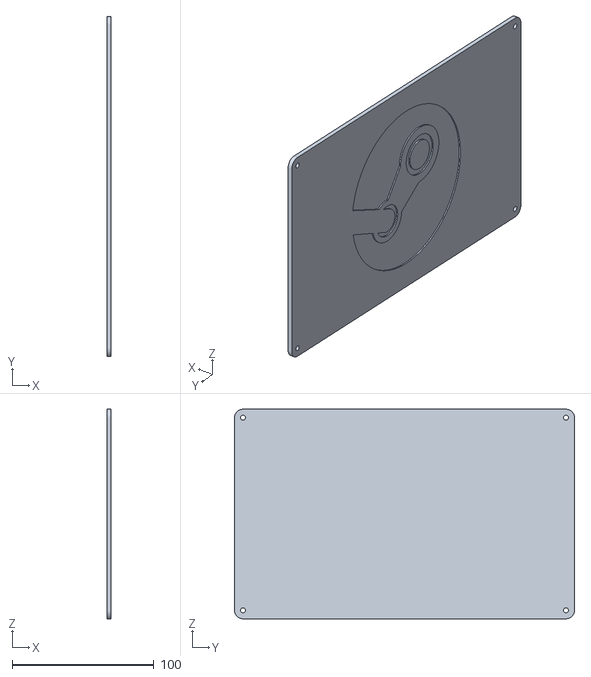
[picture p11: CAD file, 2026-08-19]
references/printables-1652979-quiet-case/Deepcool Edition - Digital Display/side-panel.stl
3.00 x 240.0 x 148.0

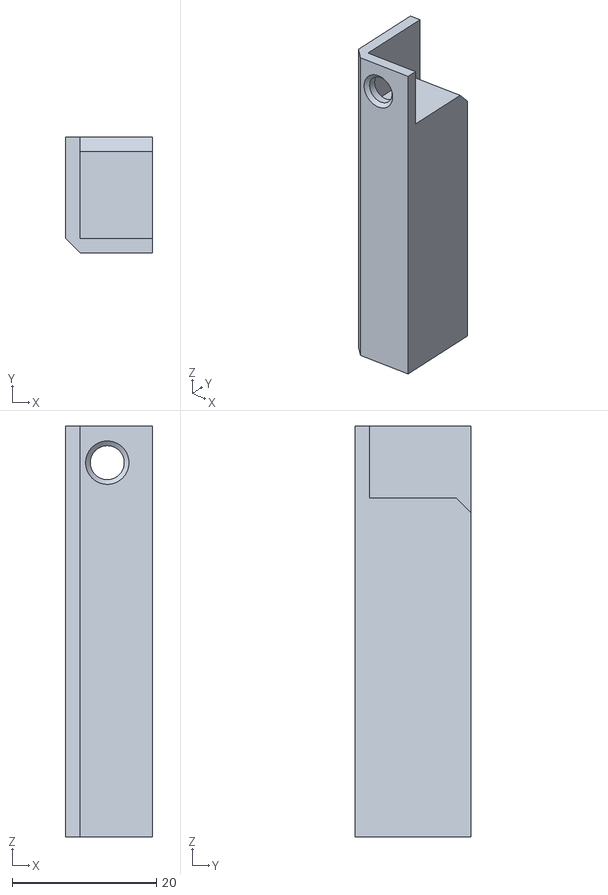
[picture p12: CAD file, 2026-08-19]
references/printables-1652979-quiet-case/XL Version - Aftermath/board-support.stl
12.0 x 16.0 x 56.9

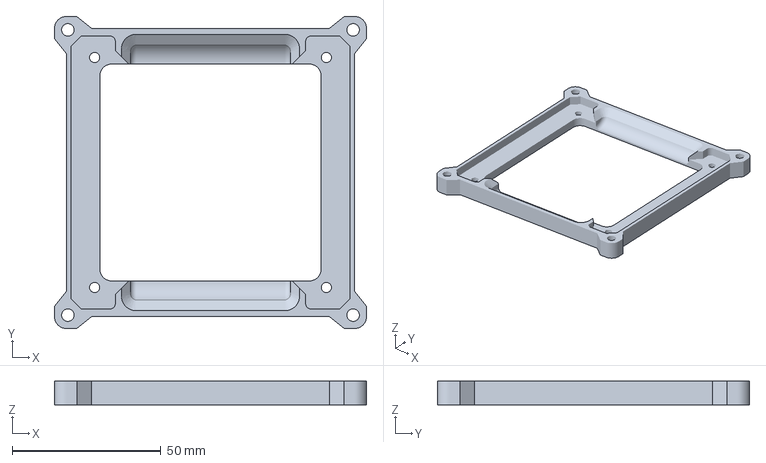
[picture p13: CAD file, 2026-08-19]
references/printables-1707972-an600-adapter/bc-250-an600.3mf
105.0 x 105.0 x 8.00 mm

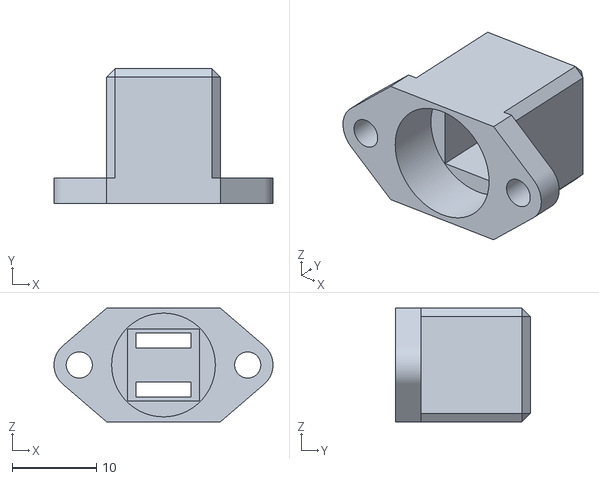
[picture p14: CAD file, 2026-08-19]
references/printables-1737913-nyacom-flex/power-btn-base.stl
26.0 x 16.0 x 13.5

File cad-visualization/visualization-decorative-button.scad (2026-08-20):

// Decorative exterior bezel for the NexGen-derived power button.
//
// Visualization-only geometry: the supplied logo cap remains a separate mesh,
// while this part gives it a deliberate exterior surround. Local X is the
// front/rear axis, with X=0 at the panel side and negative X facing outward.

$fn = 96;

outer_d = 23.6;
inner_d = 16.5;
depth = 3.8;
front_lip = 0.9;

module beveled_ring() {
    // Build around Z and rotate so the exported button axis is X.
    rotate([0, -90, 0])
        rotate_extrude(convexity = 10)
            polygon([
                [inner_d / 2, 0],
                [outer_d / 2 - 1.8, 0],
                [outer_d / 2, front_lip],
                [outer_d / 2, depth - 0.7],
                [outer_d / 2 - 0.7, depth],
                [inner_d / 2 + 0.5, depth],
                [inner_d / 2, depth - 0.5]
            ]);
}

module decorative_bezel() {
    difference() {
        beveled_ring();

        // Eight shallow grip cuts catch highlights without competing with the
        // logo. They also make the ring read as a separate machined component.
        for (angle = [0 : 45 : 315])
            rotate([angle, 0, 0])
                translate([-depth + 0.35, outer_d / 2 - 0.25, -0.65])
                    cube([1.2, 1.0, 1.3]);
    }
}

decorative_bezel();

echo("decorative_button_bezel_mm", [depth, outer_d, inner_d]);
echo("axis", "X; X=0 panel side, negative X outward");

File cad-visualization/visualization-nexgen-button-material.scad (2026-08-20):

// Export wrapper for the separated materials of the supplied NexGen cap.
//
// The source 3MF keeps the coordinates of the complete NexGen assembly.  Move
// both material bodies onto one small, shared button-local datum so the viewer
// can place the cap and logo as a single assembly instead of maintaining two
// unrelated sets of magic coordinates.  Local X is the button axis: X=0 is
// the panel-side face and negative X points out of the case.
part = "black"; // black | white

source_face_x = 3.566254;
source_center_y = 4.527873;
source_center_z = 95.01802;

module normalized_button_material(path) {
    translate([-source_face_x, -source_center_y, -source_center_z])
        import(path);
}

if (part == "black")
    normalized_button_material("../cad/vendor/nexgen/button-cap-black.3mf");
else if (part == "white")
    normalized_button_material("../cad/vendor/nexgen/button-logo-white.3mf");

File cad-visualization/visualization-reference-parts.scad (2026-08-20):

// Visualization-only exports of supplied reference components.
// These meshes remain separate from production CAD and retain their source licenses.

part = "button-plate"; // button-plate | button-light-pipe | button-cap | usb-cover

if (part == "button-plate")
    import("../references/printables-1793043-nexgen-pro-v2/Power Button/pro-v2-button-mounting-plate.3mf");
else if (part == "button-light-pipe")
    import("../references/printables-1793043-nexgen-pro-v2/Power Button/pro-v2-transparent-rear-section.3mf");
else if (part == "button-cap")
    import("../references/printables-1793043-nexgen-pro-v2/Power Button/pro-v2-steam-logo.3mf");
else if (part == "usb-cover")
    import("../references/printables-1793043-nexgen-pro-v2/Case/pro-v2-usb-cover-multi-material.3mf");

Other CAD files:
references/printables-1793043-nexgen-pro-v2/AIO Mount/clamping-plate-v2.3mf
references/printables-1793043-nexgen-pro-v2/ARGB LED Strip/pro-v2-argb-strip-mount.3mf
references/printables-1793043-nexgen-pro-v2/Case/pro-v2-rear-case-multi-material.3mf
references/printables-1793043-nexgen-pro-v2/Foot/pro-long-foot-tpu.3mf
cad/board-spine-v0.1.scad
cad/chassis-joint-coupon-v0.1.scad
cad/chassis-split-v0.1.scad
cad/core-assembly-v0.1.scad
cad/esp32-service-cover-v0.1.scad
cad/exports/chassis-joint-coupon-0.25mm-v0.1.stl
cad/exports/chassis-joint-coupon-0.45mm-v0.1.stl
cad/exports/fit-calibration-coupon-v0.1.stl
cad/exports/support-horizontal-v0.1.stl
cad/exterior-nyacom-v0.2.scad
cad/fit-calibration-coupon-v0.1.scad
cad/front-service-module-v0.1.scad
cad/intake-panel-snap-v0.1.scad
cad/layout-a-envelope.scad
cad/peripheral-bay-v0.1.scad
cad/power-button-nexgen-v0.1.scad
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

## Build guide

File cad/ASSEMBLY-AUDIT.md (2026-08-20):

# Assembly audit 2026-08-20

## Verdict

The project does **not** currently contain a complete buildable enclosure. Earlier exports mixed visual studies, equipment envelopes, calibration parts, and disconnected mechanical prototypes in one directory. They could not be assembled into one case without drilling, glue, or redesign.

All production-looking exports have therefore been withdrawn. `cad/exports/` now contains calibration coupons only.

## Interface audit

| Interface | Result | Evidence / required correction |
|---|---|---|
| Chassis front ↔ chassis rear | integrated, unvalidated | The collar aligns the sections and two bottom-access M3 screws retain them. Insert/collar coupon results remain open. |
| Intake halves ↔ chassis | blocked | Covers are raised to Z=32, their grille fields remain on the JF13K fan axes, and the ESP32 cover no longer overlaps them. STL topology still reports the two upper magnet bosses in each split core as detached islands; these bosses must be redesigned or replaced before release. Pocket fit and the perimeter seat/fascia still require a coupon. |
| Front panel ↔ chassis | integrated, unvalidated | Full 155 × 195 × 12 mm sculpted Nyacom-derived end cap matches the case section and has four front-access M3 insert bosses. Screw length and insert fit remain open. |
| Monolithic rear covers ↔ chassis | integrated, unvalidated | Both rear variants are single structural bodies on the common four-point M3 interface. Final PSU/I/O apertures remain open. |
| Button ↔ front panel | integrated, unvalidated | NexGen plate mounts entirely against the inside face; two blind M3 insert axes, central passage and a thickness extension align the external cap. Insert fit and switch travel remain open. |
| Anker A7516 cassette ↔ front panel | integrated, unvalidated | Vertical 28.6 × 71.0 mm opening, two hidden receivers, four USB-A cuts, and a 103 × 30 × 10 mm cradle are modeled. Physical fit remains open. |
| ESP32 service cover ↔ chassis | integrated, unvalidated | The solid 98 × 32 mm cover replaces a matching 3 mm shell seat and ends at the lower edge of the intake cover without overlap. It has no exterior ventilation slots or magnets and uses four hidden cantilever hooks. Envelope, rail support, cover/opening containment and cover-to-cover separation are asserted; physical snap fit remains open. |
| Board spine ↔ chassis | integrated, unvalidated | Eight transverse M4 axes now match eight webbed core bosses. M4 insert fit and load testing remain open. |
| BC-250 ↔ board spine | partially defined | Bare PCB envelope is now 308.0 × 144.3 × 1.6 mm and the split pocket is modeled; final edge clamps still require a real-board keepout check. |
| JF13K ↔ spine/chassis | partially defined | Official envelope and photo-derived placement are frozen; the spine load path reaches the shell. Non-contact transport-pad locations remain open. |
| Universal PSU receiver ↔ chassis | integrated, unvalidated | The internal 110 × 46.34 mm receiver is fused into the rear core through four side-wall bridges and stays behind X=318. Print clearance remains open. |
| NexGen PSU adapter ↔ receiver | defined, unvalidated | Server/FlexATX/LOP plate depths fit the common guides and interior clamps; print clearance remains untested. |
| Cisco PSU ↔ server adapter | reference-derived | Use the supplied NexGen universal server-PSU mount with an inward offset; no separate Cisco body measurement is required. |
| 2.5-inch cassette ↔ chassis | integrated, unvalidated | Front-load 110 × 80 mm cassette has guide walls, lips, rear stop and one accessible M3 retainer. It supports 7–15 mm devices; physical fit and cable direction remain open. |
| ESP32 cassette ↔ chassis | integrated, provisional | Horizontal 68 × 68 mm cassette has bottom guide rails, inner stop, printed detent and hidden side-service opening. Board posts and cable cuts await actual hardware. |
| Horizontal supports ↔ chassis | partially defined | Four bosses exist, but inserts and assembled fit are unvalidated. |
| Vertical rear/base cover ↔ chassis | integrated, unvalidated | The tapered cover and rear core share four M3 axes; insert fit, connector bend radius, and load test remain open. |

## Status of source models

The remaining `.scad` files are retained as design studies and reusable geometry only. They are **not release parts** and must not be sent to a print service. A source becomes releasable only after it is included in the master assembly, has a defined mating interface, passes collision checks, and receives a fresh export.

## Controlled recovery order

Confirmed architecture: BC-250 and the major internal components are vertical along the long axis, matching the Nyacom reference assembly. The earlier horizontal two-level layout is superseded.

1. Maintain `core-assembly-v0.1.scad` as the master coordinate source.
2. Complete both end-panel seats and their accessible retention.
3. Add final PCB edge clamps and non-contact JF13K transport pads after physical keepout checks.
4. Validate the integrated common PSU receiver with its clearance coupon and
   selected adapter plate.
5. Add horizontal and vertical supports against explicit chassis interfaces.
6. Freeze ESP32 sliding-post positions and cable exits after actual-board fit.
7. Run collision and manifold checks, then populate `cad/exports/release/<version>/` as one versioned set.

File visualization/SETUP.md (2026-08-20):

# Развёртывание 3D-визуализации BC-250

## Требования

- Git;
- Python 3.10 или новее;
- OpenSCAD с доступной командой `openscad` — только для пересборки STL;
- современный браузер с WebGL 2;
- интернет при открытии страницы: Three.js загружается с jsDelivr.

Установка OpenSCAD:

- macOS: `brew install --cask openscad`;
- Ubuntu/Debian: `sudo apt install openscad`;
- Windows: установить OpenSCAD и добавить его в `PATH`. Также распознаётся стандартный путь `C:\Program Files\OpenSCAD`.

## Получение проекта

```sh
git clone <URL-ЭТОГО-РЕПОЗИТОРИЯ> bc250-case
cd bc250-case
```

Mesh-модель BC-250 находится во внешнем репозитории и намеренно не коммитится
сюда из-за отсутствия явной лицензии. Для локальной инженерной визуализации:

```sh
git clone https://github.com/hafriedlander/bc250-case.git references/hafriedlander-bc250-case
git -C references/hafriedlander-bc250-case checkout cf807f35897c43f5c489bf60b8fa54bf1fba0f00
```

Без этого источника корпус откроется, но плата BC-250 не загрузится. Нельзя
включать `bc250_alt.stl` в релизные архивы до подтверждения лицензии.

## Запуск с автообновлением

```sh
python3 tools/dev_visualization.py
```

Открыть <http://localhost:8000/visualization/> и оставить команду работающей.
Остановка — `Ctrl+C`.

Watcher:

1. Запускает сервер только на локальном адресе `127.0.0.1`.
2. Следит за интерфейсом и готовыми `visualization/assets/*.stl`.
3. Автоматически перезагружает открытую вкладку после их изменения.
4. Не пересобирает `cad/` автоматически.

Принудительная полная пересборка (только по явному запросу):

```sh
python3 tools/dev_visualization.py --rebuild
```

Другой порт:

```sh
python3 tools/dev_visualization.py --port 8080
```

## Ручной экспорт

На macOS, Linux, WSL или в Git Bash:

```sh
tools/export_visualization_assets.sh
```

Единая команда аудита и обновления (`/up-model` в терминологии проекта):

```sh
tools/up-model
```

Поддерживаемое явное имя skill в Codex — `$up-model`. Режим только проверки:

```sh
tools/up-model --check
```

Команда экспортирует модели во временный каталог, сравнивает их с браузерными
STL и атомарно обновляет только `visualization/assets/`. Каталоги `cad/` и
`cad-visualization/` остаются только для чтения.

## Структура

- `cad/core-assembly-v0.1.scad` — основная сборка;
- `cad/` — авторитетный инженерный CAD, только для чтения со стороны визуализации;
- `cad-visualization/` — непечатные исходники визуализации, также только для чтения;
- `visualization/MODEL-SOURCES.md` — точная карта происхождения всех моделей;
- `visualization/viewer.js` — сцена, материалы, transforms и модель JF13K;
- `visualization/styles.css` — интерфейс;
- `tools/dev_visualization.py` — watcher и локальный сервер.

Если добавлен новый `part` или изменилась экспортная ориентация, обновить нужно
и список экспорта в watcher, и `specs` в `viewer.js`.

## Типичные проблемы

### OpenSCAD не найден

Проверить `openscad --version`. На macOS скрипт дополнительно ищет
`/Applications/OpenSCAD.app/Contents/MacOS/OpenSCAD`.

### Плата не отображается

Проверить наличие файла:

```text
references/hafriedlander-bc250-case/_extern/bc250_alt.stl
```

### Страница не открывается

Проверить, что watcher работает и порт свободен. При необходимости использовать
`--port 8080`. Открывать HTML через `file://` нельзя — браузер заблокирует STL.

### Изменения ещё не появились

Дождаться окончания сообщений `Exporting ...`. При ошибке исправить SCAD-файл;
предыдущая рабочая визуализация останется доступна.

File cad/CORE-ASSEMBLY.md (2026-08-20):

# Structural core v0.1

`core-assembly-v0.1.scad` is the first replacement built after the assembly audit. It is a single source for both shell halves and their shared interface.

## Fit is a build constraint

The assembly now defines canonical global envelopes for the usable interior,
BC-250 board, Cisco PSU, JF13K, 2.5-inch device and ESP32 bay. The same bounds
drive the diagnostic view and build-time assertions. Export stops if a major
component leaves the inner volume or if a forbidden component pair intersects.

Set `part = "fit-audit"` to see all envelopes together. The cooler proxy grows
by its mandatory 6 mm no-contact allowance; forbidden overlaps are red.
Intended contact between the cooler and its board is deliberately excluded.

The ESP32 cover is parameterised by the assembly. Its size, chassis chamfer and
magnet axes come from the same values as the opening and recessed seat.
Assertions require the cover to contain the complete opening and keep all four
magnet axes on solid material.

The component architecture follows the Nyacom reference: BC-250 is vertical in the longitudinal X-Z plane, JF13K projects toward the broad side intake, and the Cisco PSU is rotated to a 40 mm Y thickness on the opposite side of the board. The former horizontal two-level layout is superseded.

The JF13K proxy is now fixed to the official 241 × 121 × 92 mm product envelope
and centred on the locally verified 308.0 × 144.3 mm PCB datum. Supplied assembly
photographs validate the orientation and installed height. This leaves 9.4 mm
from the fan-side envelope to the inner intake-panel face; CAD rejects anything
below 6 mm. See `JF13K-PHOTO-FIT.md` for the evidence and residual checks.

The broad-side intake now consists of two chamfered 128 × 119 mm windows separated by a
real 10 mm shell rib at the chassis split. Two independent 130 × 131 mm covers
leave that rib visible. Their grille centres are fixed at global X=105 and
X=225 mm, matching the two JF13K fan centres. Eight magnet seats are
fused to the inner wall; the lower right pattern is shifted away from the ESP32
service path.

The covers repeat the same eight-sided outline with a 6 mm sealing overlap and
use a raised 108 mm circular rim around a regular hex field. The ESP32 service
extension is hidden by a recessed skirt attached to the right cover; it stays
inside the lower chassis chamfer instead of extending the exterior silhouette.

## What is now mechanically closed

- front and rear use the same 330 × 155 × 195 mm coordinate system;
- the front half carries the 9 mm octagonal alignment collar;
- a fused collar anchor joins the collar to the front shell;
- two M3 heat-set bosses sit inside the collar near the bottom seam;
- the rear half provides matching bottom-access clearance and countersink holes;
- both screws can be installed after joining the halves without reaching through the 330 mm enclosure;
- screw heads remain underneath the case and outside normal service panels.
- the separate split board spine is placed from the verified PCB datum;
- its eight transverse M4 axes now terminate in matching core bosses;
- shallow boss webs remain outside the central PSU envelope and carry the
  895 g JF13K transport load into the structural shell;
- the board/spine datum is shifted 4 mm below geometric centre, preserving
  2.65 mm between the lower 12 mm bosses and the provisional PSU envelope;
- both spine halves can be exported from the master coordinate source.
- the common NexGen 110 × 46.34 mm PSU receiver is fused into the rear core by
  four short corner bridges to the side walls;
- its rear extent stops at X=318, leaving 12 mm to the outside rear plane;
- server, FlexATX, and LOP adapter plates remain interchangeable service parts,
  while no PSU bracket protrudes outside the enclosure.
- the full-section 155 × 195 × 12 mm front cap preserves the Nyacom source
  bevels and stepped surface, closes the entire case end, and uses four
  front-access countersunk M3 screws into fused insert bosses;
- its source mesh is depth-corrected so the sculpted face points outward; the
  NexGen button mounting plate remains completely inside the enclosure;
- the panel remains separately printable and removable without opening the
  structural chassis seam.
- two ribbed M3 insert bosses now retain the NexGen-derived button plate;
- the baseline Anker A7516 hub uses a vertical 28.6 × 71.0 mm opening and a
  separately printable four-port cassette with two hidden hooks;
- the cassette carries the 103 × 30 × 10 mm hub envelope, so a future cheaper
  hub changes the cassette rather than the main front panel wherever possible.
- both rear-cover variants are monolithic, matching the source-case strategy;
  temporary board/I/O and PSU blanks have been removed. Final connector cuts
  will be made directly in each rear variant after their positions are frozen.
- the front-load 2.5-inch cassette supports 7–15 mm devices on a 76.6 × 61.72
  mm M3 pattern and slides in the free pocket ahead of JF13K;
- two guide walls, retaining lips, a rear stop and one front-access M3 screw
  form a complete chassis interface without blocking the cooler intake.
- the 68 × 68 mm ESP32 relay cassette sits horizontally under JF13K, leaving
  3.6 mm nominal clearance to the cooler envelope;
- bottom guide rails, an inner stop and a printed detent allow side removal;
  a separate 98 × 40 mm vented cover closes the 74 × 28 mm service opening.
  Its lower profile follows the 16 mm case chamfer, its upper profile is flush
  with the straight side wall, and four 8 × 2 mm magnet pairs sit on solid
  frame areas outside the opening; the bottom pry notch remains 5 × 2 mm.

## Assembly sequence for the core

1. Install two selected M3 heat-set inserts into the front-core bosses from below.
2. Slide the rear core over the alignment collar.
3. Turn the joined core upside down.
4. Install two M3 countersunk screws through the rear floor into the front-core inserts.
5. Verify that the seam closes without deforming the collar.

The exact screw length and insert pilot remain provisional until the fit coupon is measured. No release STL is published yet.

## Next required interfaces

1. Validate the 8.25 × 2.20 mm side/ESP32 magnet pockets with a small print coupon.
2. Add final connector apertures directly to both monolithic rear variants after
   cable and port alignment is frozen.
3. Physically check the Anker cassette, M3 button inserts, and switch travel.
4. Verify the selected 2.5-inch drive's SATA/power cable direction.
5. Measure the actual ESP32 relay-board hole pattern and connector exits, then
   freeze its adjustable posts.
3. Final BC-250 edge clamps and non-contact JF13K transport pads after physical
   keepout checks.
4. Two rear-cover variants on one four-point M3 interface: a shallow horizontal
   cover and a 44 mm open cable-management base for tower orientation.
4. Validate the internal PSU receiver and selected adapter with a clearance
   coupon before installing hardware.

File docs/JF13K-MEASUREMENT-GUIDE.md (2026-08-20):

# Как измерить BC-250 с установленным JF13K

> Статус: после сопоставления фотографий сборки с официальным габаритом JF13K
> эта процедура больше не блокирует проектирование корпуса. Она оставлена как
> необязательная финальная проверка перед печатью.

Ничего разбирать и откручивать не нужно. Нужны только:

- обычная линейка с миллиметрами;
- телефон;
- любой второй ровный предмет: другая линейка, угольник или ровная книжка.

Главная схема:

Что измерять

## 1. Четыре расстояния сверху

Положите плату так, чтобы кулер смотрел вверх. Сфотографируйте её строго сверху.

Измерьте расстояние от каждого края платы до края металлического радиатора:

- `A` - слева;
- `B` - справа;
- `C` - сверху;
- `D` - снизу.

Если радиатор выступает за плату, так и напишите: например,
`A = выступает на 12 мм`.

Не измеряйте до вентилятора или провода. Нужен край металлического радиатора.

## 2. Высота кулера

Посмотрите на сборку сбоку. Положите вторую линейку или ровную книжку поверх
кулера, не нажимая на вентиляторы. Другой линейкой измерьте:

- `E` - от поверхности платы до нижней стороны верхней линейки.

Это общая высота кулера над платой.

## 3. Что выступает с обратной стороны

Посмотрите на обратную сторону платы и найдите самую выступающую деталь крепления:
backplate, гайку или конец винта.

Измерьте:

- `F` - насколько эта деталь выступает ниже поверхности платы.

Если измерить неудобно, сделайте хорошую фотографию сбоку с приложенной линейкой.

## 4. Место около разъёма питания

Подключите силовой штекер так, как он будет подключён в корпусе.

Измерьте самое узкое расстояние между штекером/проводом и кулером:

- `G` - минимальный свободный зазор.

Также сфотографируйте это место крупно. Важно видеть, в какую сторону уходит
провод.

## 5. Фотографии

Нужно семь фотографий:

1. Строго сверху на всю плату и кулер.
2. Строго с обратной стороны платы.
3. Слева.
4. Справа.
5. Со стороны верхнего края платы.
6. Со стороны нижнего края платы.
7. Крупно подключённый разъём питания рядом с кулером.

На каждой фотографии положите линейку рядом с платой. Линейка и измеряемая
деталь должны находиться примерно на одинаковом расстоянии от камеры.

## Что прислать

Скопируйте этот текст и впишите числа:

```text
A слева = __ мм / радиатор выступает на __ мм
B справа = __ мм / радиатор выступает на __ мм
C сверху = __ мм / радиатор выступает на __ мм
D снизу = __ мм / радиатор выступает на __ мм
E высота кулера над платой = __ мм
F выступ с обратной стороны = __ мм
G зазор около подключённого питания = __ мм
```

И приложите семь фотографий. Если какое-то место невозможно измерить, просто
напишите `не получилось` и сфотографируйте его с линейкой - этого достаточно.

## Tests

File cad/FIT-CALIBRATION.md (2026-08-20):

# Fit calibration coupon v0.1

`fit-calibration-coupon-v0.1.scad` combines the material-dependent interfaces that must be tested before ordering full-size case prints.

The exported set contains:

- blind M3 heat-set-insert pilots: 4.0, 4.2, and 4.4 mm;
- blind M4 heat-set-insert pilots: 5.0, 5.2, and 5.4 mm;
- M3 screw holes: 3.0, 3.2, and 3.4 mm;
- M4 screw holes: 4.2, 4.4, and 4.6 mm;
- one production-size snap hook;
- three snap receivers with 0.20, 0.30, and 0.40 mm clearance per side.

## Test procedure

1. Print the coupon in the same material, layer height, wall count, orientation, and printer profile planned for the case.
2. Measure every hole with calipers before installing hardware; record nominal and measured diameters.
3. Install only the exact insert model intended for the build. The insert must enter straight without splitting or visibly bulging the wall.
4. Check M3 and M4 screws by hand. Select the smallest through-hole that does not require threading or excessive force.
5. Test the hook in all three receivers for at least ten insertion/removal cycles. Reject whitening, root cracks, permanent bending, excessive play, or destructive release force.
6. Record the selected values below and update `lib/snap-interface.scad`, `lib/common.scad`, `chassis-split-v0.1.scad`, and `BOM.md` before printing full panels.

## Results

| Parameter | Selected nominal value | Measured printed value | Material/profile | Notes |
|---|---:|---:|---|---|
| M3 insert pilot | — | — | — | — |
| M4 insert pilot | — | — | — | — |
| M3 clearance hole | — | — | — | — |
| M4 clearance hole | — | — | — | — |
| Snap clearance per side | — | — | — | — |

Do not infer the final pilot diameter only from the insert's outside diameter. Heat-set insert geometry and manufacturer recommendations differ.

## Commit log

2026-08-19 Initialize BC-250 JF13K case research
    [asrock_bc-250-case_flexatx_bodyprod_x2d.3mf, asrock_bc-250-case_v21_flexatx.3mf, back-case.stl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]
2026-08-19 Add initial enclosure architecture report
2026-08-19 Add validated layout A envelope CAD
    [layout-a-envelope.scad, layout-a-envelope.stl]
2026-08-19 Add interchangeable horizontal and vertical supports
    [support-horizontal-v0.1.stl, support-horizontal.scad, support-vertical-v0.1.stl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]
2026-08-19 Add Steam Machine exterior concept
    [exterior-concept-horizontal-v0.1.3mf, exterior-concept-v0.1.scad, exterior-concept-vertical-v0.1.3mf]
2026-08-19 Replace exterior with Nyacom adaptation
    [exterior-concept-horizontal-v0.1.3mf, exterior-concept-v0.1.scad, exterior-concept-vertical-v0.1.3mf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]
2026-08-20 Correct Nyacom chassis proportions
    [exterior-nyacom-horizontal-v0.2.3mf, exterior-nyacom-v0.2.scad, exterior-nyacom-vertical-v0.2.3mf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]
2026-08-20 Split structural chassis for printing
    [chassis-front-v0.1.stl, chassis-rear-v0.1.stl, chassis-split-v0.1.scad]
2026-08-20 Add snap-fit split intake panels
    [intake-panel-left-v0.1.stl, intake-panel-right-v0.1.stl, intake-panel-snap-v0.1.scad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]
2026-08-20 Add NexGen button emblem and project attribution
    [power-button-nexgen-v0.1.3mf, power-button-nexgen-v0.1.scad, power-button-nexgen-v0.2.3mf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]
2026-08-20 Add modular front service panel
    [front-panel-nyacom-v0.1.stl, front-service-module-v0.1.scad, usb-hub-cassette-v0.1.stl]
2026-08-20 Add split BC-250 structural board tray
    [board-tray-front-v0.1.stl, board-tray-rear-v0.1.stl, board-tray-v0.1.scad]
2026-08-20 Integrate chassis tray and internal PSU layout
    [integration-assembly-v0.1.scad]
2026-08-20 Correct integration assembly export note
2026-08-20 Add SSD and ESP32 peripheral cassettes
    [esp32-relay-cassette-v0.1.stl, peripheral-bay-v0.1.scad, ssd7-cassette-v0.1.stl]
2026-08-20 Integrate snap receivers and tray ledges into chassis
    [chassis-front-v0.1.stl, chassis-front-v0.2.stl, chassis-rear-v0.1.stl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]
2026-08-20 Add flush modular rear service system
    [rear-cisco-insert-v0.1.stl, rear-flexatx-insert-v0.1.stl, rear-io-blank-v0.1.stl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]
2026-08-20 Add reinforced horizontal support interface
    [chassis-front-v0.2.stl, chassis-front-v0.3.stl, chassis-rear-v0.2.stl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]
2026-08-20 Add provisional assembly BOM and procurement list
2026-08-20 Add combined mechanical fit calibration coupon
    [fit-calibration-coupon-v0.1.scad, fit-calibration-coupon-v0.1.stl]
2026-08-20 Add printable chassis joint calibration set
    [chassis-front-v0.4.stl, chassis-joint-coupon-0.25mm-v0.1.stl, chassis-joint-coupon-0.35mm-v0.1.stl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]
2026-08-20 Audit assembly and remove misleading prototype exports
    [board-tray-front-v0.1.stl, board-tray-rear-v0.1.stl, chassis-front-v0.3.stl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]
2026-08-20 Start vertical Nyacom-style master assembly
    [core-assembly-v0.1.scad]
2026-08-20 Add NexGen Redux reference and adaptation notes
    [blank-button-for-fsp500-pcb.3mf, blank-button-for-generic-latching-switch.3mf, blank-button-to-convert-switch-to-momentary.3mf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]
2026-08-20 Add dual rear covers and vertical tower visualization
    [bc-250-mk7.stl, core-assembly-v0.1.scad]
2026-08-20 Replace contradictory case preview with orthographic views
2026-08-20 Integrate tapered vertical rear cover
    [core-assembly-v0.1.scad]
2026-08-20 Add dimensional vertical BC-250 board spine
    [board-spine-v0.1.scad, board-tray-v0.1.scad, core-assembly-v0.1.scad]
2026-08-20 Add internal PSU receiver and JF13K measurement guide
    [psu-universal-internal-v0.1.scad, psu-universal-internal-v0.2.scad, rear-service-system-v0.1.scad]
2026-08-20 Validate JF13K fit from assembly photos
    [core-assembly-v0.1.scad, intake-panel-snap-v0.1.scad]
2026-08-20 Integrate vertical board spine with chassis
    [core-assembly-v0.1.scad]
2026-08-20 Integrate internal universal PSU receiver
    [core-assembly-v0.1.scad]
2026-08-20 Integrate recessed snap-fit front panel
    [core-assembly-v0.1.scad]
2026-08-20 Add shared snap-fit rear service blanks
    [core-assembly-v0.1.scad, rear-service-blanks-v0.1.scad]
2026-08-20 Integrate NexGen Anker hub and button mounts
    [core-assembly-v0.1.scad, front-service-module-v0.1.scad]
2026-08-20 Integrate front-load 2.5-inch drive bay
    [core-assembly-v0.1.scad, peripheral-bay-v0.1.scad]
2026-08-20 Integrate side-load ESP32 relay cassette
    [core-assembly-v0.1.scad, peripheral-bay-v0.1.scad]
2026-08-20 Add coherent browser assembly visualization
    [board-spine-front.stl, board-spine-rear.stl, button-cap-black.stl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]
2026-08-20 Align JF13K covers with chassis chamfers
2026-08-20 Split JF13K intake around structural rib
    [core-assembly-v0.1.scad, front-core.stl, intake-cover-left.stl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]
2026-08-20 Redesign JF13K intake covers and openings
    [core-assembly-v0.1.scad, front-core.stl, intake-cover-left.stl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]
2026-08-20 Replace service panel hooks with magnets
    [core-assembly-v0.1.scad, front-core.stl, front-panel.stl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]
2026-08-20 Rebuild front and rear service panels
    [board-spine-front.stl, board-spine-rear.stl, button-logo-white.stl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]
2026-08-20 Replace front insert with sculpted Nyacom end cap
    [core-assembly-v0.1.scad, front-core.stl, front-panel.stl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]
2026-08-20 Flip front cap and mount NexGen button internally
    [core-assembly-v0.1.scad, front-core.stl, front-panel.stl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]
2026-08-20 Make ESP32 service cover flush with chassis
    [core-assembly-v0.1.scad, esp32-cover.stl, esp32-service-cover-v0.1.scad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]
2026-08-20 Refresh generated front chassis asset
    [front-core.stl]
2026-08-20 Add assembly-wide fit constraints
    [core-assembly-v0.1.scad, esp32-service-cover-v0.1.scad, front-core.stl]
2026-08-20 Enforce shared case interface contracts
    [core-assembly-v0.1.scad, esp32-service-cover-v0.1.scad, front-service-module-v0.1.scad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]
2026-08-20 Fix ESP32 service cover snap interface
    [core-assembly-v0.1.scad, esp32-cover.stl, esp32-service-cover-v0.1.scad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]
2026-08-20 Align ESP32 lower snaps with case chamfer
    [core-assembly-v0.1.scad, esp32-cover.stl, esp32-service-cover-v0.1.scad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]
2026-08-20 Adopt Nyacom structural rails and airflow paths
    [core-assembly-v0.1.scad, front-core.stl, rear-core.stl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]
2026-08-20 Revert "Adopt Nyacom structural rails and airflow paths"
    This reverts commit db4a3ba9c65aadcef4ede265bbbeb729fd6cedf0.
    [core-assembly-v0.1.scad, front-core.stl, rear-core.stl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]
